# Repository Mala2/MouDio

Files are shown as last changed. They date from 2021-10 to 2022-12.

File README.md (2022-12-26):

<p align="center">
     

</p>
<p align="center">
	<a href="https://github.com/Mala2/Bluetooth-Speaker/repo-size" alt="repo-size">
		</a>
	<a href="https://github.com/Mala2/Bluetooth-Speaker/issues" alt="Issues">
		</a>
	<a href="https://github.com/sparkfun/Qwiic_SerLCD_Py/blob/master/LICENSE" alt="License">
		</a>
	  <br/>
  	<a href="https://discord.gg/jvKunuGb8d">
   		
	<a href="https://twitter.com/intent/follow?screen_name=Muhammadalali">
        	</a>
	<a href="https://github.com/Mala2">
        	</a>
	<a href="https://github.com/Mala2/Bluetooth-Speaker/stargazers" alt="stars">
		</a>

<p align="center">
🚨 ⚠ This project is currently still under development ⚠️ 🚨

<p align="center">
     
   
<p align="center">
(https://www.MouDio.net)
</p>

# Overview
Introducing the fully functional Bluetooth Speaker, featuring modern design and high-performance capabilities. With the choice of ATmega328P or ESP32 microcontroller at its core and compatibility with Arduino & Platformio, this portable speaker offers easy construction, allowing users to quickly and easily set it up, and the high-quality audio ensures that your music will sound great.

The speaker also boasts the Qualcomm® CSR8675 FSC-BT806 and 2x Texas Instruments® TAS5825M amplifiers, providing low distortion and powerful output of 2 x 30 W.

The PCB prototypes have been built and tested, with excellent results. The hardware design is complete, and we are now focusing on the software development. We invite you to explore the shared files for more information on this exciting project.

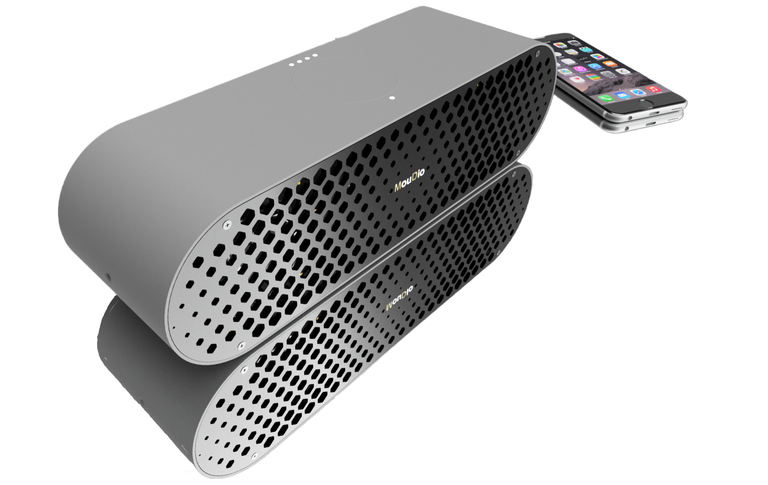
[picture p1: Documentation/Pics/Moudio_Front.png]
(https://a360.co/3340jVi)


[*🎨 View on FUSION 360*](https://a360.co/3Bk0sSi)
<p align="center">
     

# Features
	
* **Amplifier** - 2x  Texas Instruments® [*TAS5825M*](https://www.ti.com/product/TAS5825M) Which has low distortion can output 2x 30 W, 2.2 Mode (8-Ω, 24 V, THD+N=1%)
* **Connectivity** - The [*FSC-BT806 Feasycom*](https://github.com/Mala2/FSC-BT806) features
 Qualcomm® **CSR8675** - **Bluetooth V5.0** Support HSP, HFP, A2DP, AVRCP, PBAP,MAP,SPP,BLE profile - Coverage up to 15m - 2 microphone inputs - **Audio interfaces:** I²S/PCM and SPDIF

* **Power** - Accept **USB C IN** Delivery **Up to 2.5A  Charge Current**  - **USB A OUT** Capable of **10W-5V,2A** - **Low idle power** consumption - **7500mAh** battery capacity upgradeable to **15000mAh**

* **Arduino IDE Programmable Bluetooth-Speaker**
<p align="center">
     

 # Repository Contents

👩‍🚀 **[3D Files ](3D-Files)** • The **Bluetooth-Speaker** components in many formats (probably what you are looking for to 3d print)

🔉 **[Hardware](Hardware)** • The internal PCBs files (Gerber, Schematic)

💻 **[Software](Software)** • Codes and Libraries for use with the **MouDio**

📄 **[Documentation](Documentation)** • Datasheets, other references

🎲 **[Prototype](Prototype)** • Evaluation board, Cases, etc.

<p align="center">
     

# Block Diagram

The following displays the latest Block Diagram; Things may change, and probably there may be some discrepancy between the schematic and the block diagram.
	


<p align="center">
     

# Schematics

The following displays the ****[TOP Main](Documentation/TOP-Main/)**** PCB. It contain the Atmega328|ESP32 uC, LED Driver, Haptic Driver, RTC, Touch Sensor (TPR54|48), EEPROM*, Supervisory, Addressable LEDs
	

	


****[V1](Hardware/TOP/)****
	
[📐 *View on FUSION 360*](https://a360.co/3VPY0L3)

<p align="center">
     
	
The following displays the ****[BACK Charger](Documentation/BACK-Charger/)**** PCB.It contain MAX77961 3S Charger, MAX17320 Fuel Gauge, MAX25231ATCA 5V Buck, MAX77503BEWC33 3V3 Buck, 3S Battery.


	



****[V1](Hardware/BACK/)****
	
[📐 *View on FUSION 360*](https://a360.co/3UELmh8)
	
<p align="center">
     
	
The following displays the ****[BOTTOM Amplifier](Documentation/BOTTOM-Amplifier/)**** PCB.It contain the Amplifier - 2x Texas Instruments® TAS5825M and The FSC-BT806 Feasycom Bluetooth Moduel.


	

	
	
****[V1](Hardware/BOTTOM/)****	
	
[📐 *View on FUSION 360*](https://a360.co/3FziKBq)

<p align="center">
     
	
The following displays the ****[FRONT Speaker](Documentation/FRONT-Speaker/)**** PCB.To hold the Speakers and front acrylic grill


	



****[V1](Hardware/FRONT/)****
	
[📐 *View on FUSION 360*](https://a360.co/3BfI0KE)

<p align="center">
     	

# Working Principal

**1. First, I am going to use the TPR54 Touch Sensor Modules to turn ON/OFF the system, if pin [I/O-2] "TAP" it is pressed >2s. This module can send  active High signal output to the ATmega328p pin 2 [INT0].**

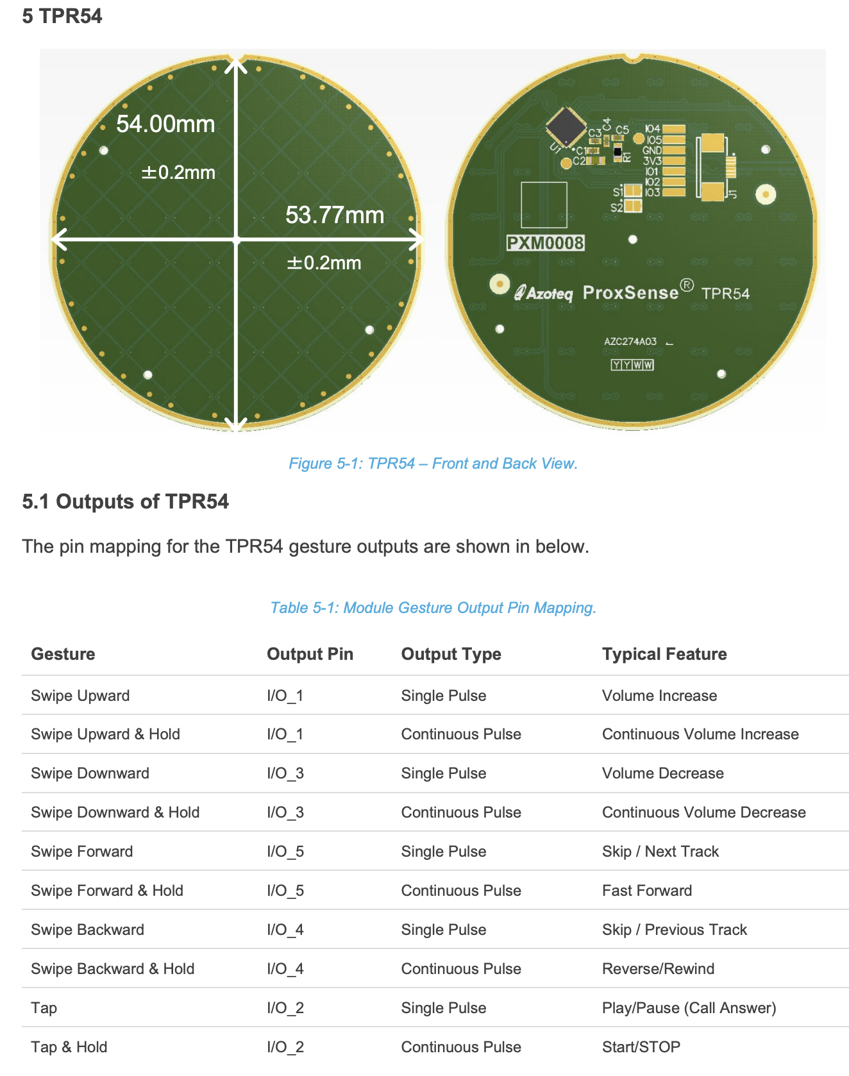
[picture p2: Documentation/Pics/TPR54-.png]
(https://www.azoteq.com/images/stories/pdf/proxsense_gpio_trackpad_datasheet.pdf)


**2. After waking up, the ATmega328 will send a high signal to turn on the Bluetooth Module BT-806 through pin [8] "Vreg" and the TAS5825 circuitry through pin [A3] "PDN".**

🔸	**Startup Procedures: [I/O_2] "TAP" pressed for >2s**

*	The ATmega328p wakes up upon High signal on pin 2 [INT0].

*	Send a 3V3 high signal to haptic driver to enable the IC.

*       initialize the LED driver IS31FL3195 to wakeup.

*	Turn on the haptic driver as an indication for 1s.

*	Turn on the LED driver to play a motion from left to right as wake up inication.

*	Turn on the LED driver to reflect the current SOC% of the battery with the help of the fuel gauge MAX17320 and check whether the charger is presnt or not set the LEDs accordingly. 

*	Send a 3V3 high signal of more than 100ms to Bluetooth Module BT-806 through VREG_IN (PLAY/PAUSE) pin to boot the module, then bring the signal back to low.

*	Once power supplies are stable, bring up PDN of TAS5825 to High and wait 5ms.

*	Set the Amplifier TAS5825 into the HiZ state and enable DSP via the I2C control port.

*	Wait 5ms at least. Then initialize the DSP Coefficient, then set the TAS5825 to Play state.

*       initialize the charger MAX77961.

	<br />
	
🔸	**Shutdown Procedures: [I/O_2] "TAP" pressed for >2s**

*	Configure the Register 0x03h -D[1:0]=10 (Hiz) via the I2C control port and Pull PDN low.

*	Wait at least 6ms (this time depends on the LRCLK rate, digital volume, and digital volume ramp-down rate).

*	Send a 3V3 high signal of more than 100ms to Bluetooth Module BT-806 through VREG_IN (PLAY/PAUSE) pin to turn off the module, then bring the signal back to low.

*	The ATmega328 goes to deep sleep, waiting for the next event.
	
	<br />

🔸	**Charging Procedures:**

*	Once the charge input is present, the MAX77961 will send an interrupter either through INTB, INOKB pins

*	Turn on the haptic driver as an indication for 1s.

*	Display the current SOC% with 4 LEDs with the help of an LED driver as long as the charge input is present. Otherwaise, the ATmega328 goes to deep sleep, waiting for the next event.

<br />
	
**3. Once the speaker is ON, the TPR54 is responsible for interacting with Bluetooth Module BT-806 to change the song and volume. (Keep in mind that the TAS5825 can also change just the volume) through TX/RX UART pin between the ATmega328 and Bluetooth Module BT-806 at 115200 rate data. For example: Once the ATmega328 is connected to BT-806, It can send a command to change the volume. For example,**



**And so on. Also, if the BAT SOC% is low, alert the user with an LED blinking and start the Shutdown Procedures once the BAT is too low to operate the system > 15%.**

# To Do List

♦️ **Need help with software part.**

1- After making sure the BT806 is OFF through the commands AT+, Turns the BT806 after turning the 3v3. Sending a high signal to Vreg for > 2s upon waking up, then remain Low. (OR MOSFET NETWORK)
	
2- If the battery is < 15%, shut down the speaker if no charging is present.
			     
✅ 3- If the battery is <35%, set the MAX volume to be less than 70%. In other words, it reduces the volume to not consume more power. TAS5825 has register 0x4c and 0x54 (AGAIN or DIGITAL_VOL) to set that.

4- (after checking the vol range of bt806), send a command AT+SPKVOL and check the volume range of BT806 sent. After that, set the TAS5825 accordingly; that can be done with two registers, either 0x4c and 0x54 (AGAIN or DIGITAL_VOL).
	
✅ 5- For example, once the user swap to the right (Next Song). The LEDs should indicate that from left to right emotions.

6- If no sounds or connection is established for 30 min, turn off the speaker. Either by checking the current flow from the fuel gauge MAX17320 or the BT-806 is not in play status or the TAS5825 register 0x03 is mute status for more than 30 min.

✅ 7- If the charger is inserted, activate the haptic driver as feedback.

9- If the charger is inserted, increase the volume range to be even higher as more power will be provided. This can be done if the 0x4C register is changed accordingly with the attached and disattached of the charger.

10- Add resetFunc() after touching the middle TAP more than 10s.

11- Get the header file for the TAS5825M to act as Dual stereo 2.2 and output the best sounds. You need PPC3 software and hardware access to test the setup and extract the best DSP settings.

12- Create the initialization code configuring the bq28z610 fuel gauge to work with the Arduino Uno and create a Library, and also create a “control” object for the bq28z610 fuel gauge. This includes configuring the IC’s registers via I2C to set configurations. In addition, looking to expose all features of the target ICs in code so that a user can easily configure those features using variables.

♦️ TO BE CONTINUED
	<p align="center">
     
# Components

🔷 **Speakers**

<p align="center">
     

[*ND65-8 2-1/2"*](https://www.parts-express.com/Dayton-Audio-ND65-8-2-1-2-Aluminum-Cone-Full-Range-Driver-8-290-206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) **X2**

🔷 **Tweeters**

<p align="center">
     

[*ND20FA-6 3/4"*](https://www.parts-express.com/Dayton-Audio-ND20FA-6-3-4-Soft-Dome-Neodymium-Tweeter-275-030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) **X2**

🔷 **Acousta-Stuf Polyfill**

<p align="center">
     

[*Acousta-Stuf Polyfill*](https://www.parts-express.com/Acousta-Stuf-Polyfill-1-lb.-Bag-260-317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)

🔷 **Brass Threaded Metal**
M3 3mm M3-0.5 Brass Threaded Metal Heat Set Screw Inserts for 3D Printing

<p align="center">
     

[*Brass Threaded Metal*](https://www.ebay.com/itm/292174792941)

🔷 **Silicone Rubber Mat 60x8x3mm**

<p align="center">
     

[*Silicone Rubber Mat*](https://www.aliexpress.com/item/3256801841973589.html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)**X2**

Mo's github stats (https://github.com/anuraghazra/github-readme-stats)
<p align="center">


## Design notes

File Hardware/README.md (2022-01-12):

Components
========================================

Speakers
--------------
ND65-8 2-1/2" (https://www.parts-express.com/Dayton-Audio-ND65-8-2-1-2-Aluminum-Cone-Full-Range-Driver-8-290-206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)

[*ND65-8 2-1/2"*](https://www.parts-express.com/Dayton-Audio-ND65-8-2-1-2-Aluminum-Cone-Full-Range-Driver-8-290-206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) **X2**

OR

[*ND65-4 2-1/2"*](https://www.parts-express.com/Dayton-Audio-ND65-4-2-1-2-Aluminum-Cone-Full-Range-Driver-290-204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) **X2**

Tweeters
--------------
Tweeters (https://www.parts-express.com/Dayton-Audio-ND20FA-6-3-4-Soft-Dome-Neodymium-Tweeter-275-030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)

[*ND20FA-6 3/4"*](https://www.parts-express.com/Dayton-Audio-ND20FA-6-3-4-Soft-Dome-Neodymium-Tweeter-275-030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) **X2**

Chemcast Black LED Acrylic
--------------
Chemcast Black LED Acrylic (https://www.tapplastics.com/product/plastics/cut_to_size_plastic/black_led_sheet/668)

[*Chemcast Black LED Acrylic*](https://www.tapplastics.com/product/plastics/cut_to_size_plastic/black_led_sheet/668) **X1** For the front panel done by laser cut

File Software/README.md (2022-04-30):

To Do List
-------------------
	
🔴 **Need help with software part.**

1- ✅ Turns the bt806 after turning the 3v3. Sending a high signal to Vreg for > 2s Upon waking up then remain Low. (OR MOSFET NETWORK)

2- ✅ if the battery < 15% shut down the speaker. 

3- ✅ if the battery <35% set the MAX volume to be less than 70%. In other words reduces the volume to not consume more power. TAS5825 has register 0x4c and 0x54 (AGAIN or DIGITAL_VOL) to set that.

4- (after checking the vol range of bt806), send a command AT+SPKVOL and check the volume range of bt806 sent. After that set the TAS5825 accordingly. That can be done with two registers either  0x4c and 0x54 (AGAIN or DIGITAL_VOL).

5- ✅ For example once the user swap to right (Next Song). The leds should indicate that. From left to right emotions ->.

6- If no sounds or connection established for 30 min turn off the speaker. Either by checking the current flow from the fuel gauge or the BT-806 is not in play status for more than 30 min. Also, it can be done through GPIO1 of TAS5825 as it will set HIGH/LOW once no sound signal is coming. 

7- ✅ If charger inserted activate the haptic driver as a feedback.

9- If the charger is inserted increase the volume range to be even higher as more power will be provided. 
	
10- add resetFunc() after touching the middle TAP more than 10s. 
	
11- get the header file for the TAS5825M to act as  Dual stereo 2.2.  
	
🔴 **To be continued

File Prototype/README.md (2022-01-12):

Bunch of Evaluation boards to determain the best suitable ICs to implement on the final design.

Please refer to the shared files for more information about specific PCB.

🎨 📐 FUSION 360 (https://d2t1xqejof9utc.cloudfront.net/screenshots/pics/dff4e49b7d47001b7a706a3b311ecfec/original.png)

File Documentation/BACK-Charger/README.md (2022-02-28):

This PCB has the Atmega328, RP2040 uC, and MAX77962 2S charger IC, BQ28Z610 Fuel Gauge IC, IS31FL3195 LED Driver IC, DRV2605 Haptic Driver IC

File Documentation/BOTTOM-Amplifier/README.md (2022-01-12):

# Main-PCB
<p align="center">

This PCB has the amplifier, and Bluetooth module BT-806 

🔴 Amplifier (TAS5825)	<a href="https://www.ti.com/product/TAS5825" alt="repo-size">
		</a>
-------------------
 The reason behind this choice contains a lot of factors. There was many potential Amplifiers for this design. Including:

To choose the suitable one I considered the key measurements are:

- SNR
- PSRR
- Efficiency
- CMRR
- Quiescent current
- THD+NOISE
- Output noise
- Crosstalk

For the SNR (Signal-to-noise ratio):

1. 🔹TPA3116, TPA3130 **102db**
2. MAX98306 ➡️ **99db**
3. SSM2302 ➡️ **98db**
4. MAX9736 ➡️ **97db**
5. PAM8403 ➡️ **80db**

**Clearly the winer here is TPA3130, TPA3116**

For the PSRR (Power supply rejection ratio):

**TPA3130 along with MAX98306 has the best performance**

For the Efficiency:
1. MAX98306 ➡️ **92\%**
2. 🔹TPA3130 ➡️ **90\%**
3. MAX9736 ➡️ **88\%**
4. PAM8403 ➡️ **87\%**
5. SSM2301 ➡️ **85\%**

**Again TPA3130 along with MAX98306 has the best performance**

For the CMRR (Common-mode rejection ratio):
1. MAX98306 ➡️ **79db**

No available data for the rest

 For the  Quiescent current:

1. MAX98306 ➡️ **2 mA**
2. 🔹TPA3130 ➡️ **4 mA**
3. PAM8403 ➡️ **16 mA**
4. MAX9736 ➡️ **30 mA**
5. TPA3116 ➡️ **32 mA**

For the THD+NOISE:

**Most of the amplifiers has approximately the same results.**

For the Output noise:

1. MAX98306 ➡️ **29uV**
2. SSM2302 ➡️ **35uV**
3. 🔹TPA3130 ➡️ **65uV**
4. MAX9736, PAM8403 ➡️ **100uV**

**We can see how **MAX98306** has a good performance**

Lastly the Crosstalk:  
1. MAX98306
2. 🔹TPA3130
3. SSM2302
4. MAX9736
5. PAM8403

**Again TPA3130 along with MAX98306 has the best performance**

Final Decision  
-------------------

**MAX98306 and (TPA3130 OR TPA3129) has the best results even though MAX98306 is better I would rather choose (TPA3130 OR TPA3129) for the output power reaching 30W in Mono setup and 2X15W in Stereo setup while MAX98306 can only output 3.7W which wasn’t enough for this Design.**

 TPA3130 and TPA3129 Both have the same footprint which make it easier to populate either one. The difference is that TPA3129 has **Low idle power** consumption. Both are capable of outputing 30W , 2X15W.

	🔺 **TAS5825M OR TAS5825P** Will be the upgrade of the (TPA3130 OR TPA3129) since it has lower distortion and built in DSP (Digital Signal Processing), plus it can output 38-W stereo which is more than enough. Only draw back is it does needs uC to configure it.

🔴 Bluetooth module (BT-806)   <a href="https://www.feasycom.net/dual-mode-bluetooth-module/bluetooth-5-0-csr8675-aptx-audio-module-fsc.html
" alt="repo-size">
		</a>
-------------------

The Bluetooth module is critical piece of the design, a lot of thoughts went into this. The [*FSC-BT806 Feasycom*](https://github.com/Mala2/FSC-BT806) has a great module which integrate the Qualcomm® CSR8675 - Bluetooth V5.0 Support HSP, HFP, A2DP, AVRCP, PBAP,MAP,SPP,BLE profile - Coverage up to 15m - True Wireless Stereo to share BT audio stream between two Speakers - Wired analog input.

This chip can output stero mode with high sound quality, plus it is easy to program which I did not get deep into. I was able to change the Bluetooth discoverable name as I wish. Through **TX/RX** pins it can communicate to other microcontrollers. I for sure haven’t used all the potential futures this Module can offer due to my luck of coding experience. Otherwise this chip is a uC and can be the master mind to control all this chips this design needs through I2C, PIOs, AIOs and LEDs for status indications (Low Battery, Bluetooth Status). Also, it supports **ANCS** The purpose of the Apple Notification Center Service (ANCS) is to give Bluetooth accessories (that connect to iOS devices through a Bluetooth low-energy link) a simple and convenient way to access many kinds of notifications that are generated on iOS devices. Finally, it can charges the battery with 200mA which wasn’t practical in this design since it has 5000mAh battery which will take up to 25 Hours for full charge. However, it would be suitable for smaller Speaker design.

To be continued ...

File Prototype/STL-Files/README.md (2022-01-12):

[*🎨 📐View and Download on FUSION 360*](https://a360.co/3340jVi)

Downloadable formats:

**STL**

**FBX**

**STEP**

**DWG**

**DXF**

**OBJ**

# Print Settings


Printer brand:
**Creality**

Printer:
**Ender-3**

Rafts:
**Doesn't Matter**

Supports:
**YES**

Resolution:
**Recommended 0.12mm** but 0.28 is alright

Infill:
**25%**

Nozzle:
**0.2-0.4mm**

Filament brand:
[**AMOLEN**](https://www.amazon.com/gp/product/B0721SVW3L/ref=ppx_yo_dt_b_asin_title_o01_s00?ie=UTF8&psc=1)

Filament color:
**Marble**

Filament material:
**PLA**

Software:
**Cura**

Notes:
The Ender-3 plate in Cura won't fit the Main body, so we have to extend the plate dimensions by a bit from Cura settings. Also, enable ironing choice for smoother finishing

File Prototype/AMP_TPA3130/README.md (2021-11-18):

I added there diffrent PCBs design on the **[PCM1820](/Prototype/ADC_PCM1820/)** PCB for the input capacitor to test diffrent values and Cap materials.

Input capacitors
-------------------

•  **Film SMT Caps** P/N: 4.7uF [35MU475KC44532](https://www.digikey.com/en/products/detail/rubycon/35MU475KC44532/9951738) 

•  **CER SMD Caps** P/N: 1uF [C1608X7R1C105K080AC](https://www.digikey.com/en/products/detail/tdk-corporation/C1608X7R1C105K080AC/634395) - 4.7uF [CGA4J3X7R1C475K125AB](https://www.digikey.com/en/products/detail/tdk-corporation/CGA4J3X7R1C475K125AB/2672862) - 10uF [CC0805KKX7R5BB106](https://www.digikey.com/en/products/detail/yageo/CC0805KKX7R5BB106/5195283)
 
•  **Film TH Caps** P/N: 4.7uF [R75PW447050H3J](https://www.digikey.com/en/products/detail/kemet/R75PW447050H3J/12144250) 

I added a dot • to indicate the right corresponding position to the main PCB

Those little PCBs can also be mounted as an **Input capacitors** on the **[PCM1820](/Prototype/ADC_PCM1820/)** PCB

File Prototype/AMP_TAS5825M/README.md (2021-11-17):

# TAS5825M OR TAS5825P

It is a class D amplifier with 90 mΩ RDS. It can output 2 × 30 W, at 24V on 8Ω driver load.

I initially intended to use **TAS5825M** but I found out that **TAS5825P** has Hybrid Pro algorithm to extend the battery life by more than 50% and it is pin-pin compatible with **TAS5825M**.

The [*FSC-BT806 Feasycom*](https://github.com/Mala2/FSC-BT806) can output analog which can be fed to the ADC **PCM1820** PCB to output 32-bits, 2-channel I2S/TDM then that can be fed to amplifier **[TAS5825M](/Prototype/AMP_TAS5825M/)** PCB. Also,The [*FSC-BT806 Feasycom*](https://github.com/Mala2/FSC-BT806) can output 2-channel I2S to directly connect to **[TAS5825M](/Prototype/AMP_TAS5825M/)** PCB if that desirable.

Power Supply 
-------------------
Voltage: 4.5-26V, recommended 12-24V

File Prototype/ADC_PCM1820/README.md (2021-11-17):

# PCM1820

It is an **ADC** with resolution of 32-bit I2S/TDM

The [*FSC-BT806 Feasycom*](https://github.com/Mala2/FSC-BT806) can output analog which can be fed to the ADC **PCM1820** PCB to output 32-bits, 2-channel I2S/TDM then that can be fed to the amplifier **[TAS5825M](/Prototype/AMP_TAS5825M/)** PCB

I added there diffrent PCBs design for the input capacitor to test diffrent values and Cap materials

Input capacitors
-------------------

•  **Film SMT Caps** P/N: 4.7uF [35MU475KC44532](https://www.digikey.com/en/products/detail/rubycon/35MU475KC44532/9951738) 

•  **CER SMD Caps** P/N: 1uF [C1608X7R1C105K080AC](https://www.digikey.com/en/products/detail/tdk-corporation/C1608X7R1C105K080AC/634395) - 4.7uF [CGA4J3X7R1C475K125AB](https://www.digikey.com/en/products/detail/tdk-corporation/CGA4J3X7R1C475K125AB/2672862) - 10uF [CC0805KKX7R5BB106](https://www.digikey.com/en/products/detail/yageo/CC0805KKX7R5BB106/5195283)
 
•  **Film TH Caps** P/N: 4.7uF [R75PW447050H3J](https://www.digikey.com/en/products/detail/kemet/R75PW447050H3J/12144250) 

I added a dot • to indicate the right corresponding position to the main PCB

Those little PCBs can also be mounted as an **Input capacitors** on the **[TAS5825M](/Prototype/AMP_TAS5825M/)** PCB

Power Supply 
-------------------
Voltage: 5V choose to populate either **BL9198-33** or **LP5912-3.3** LDO. I prefare the **LP5912-3.3** as it has LOW IQ and LOW Noise

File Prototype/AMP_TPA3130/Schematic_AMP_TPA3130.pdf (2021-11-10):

A | A
B | B
C | C
D | D
E | E

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
TITLE:
AMP_TPA3130 | REV: 1.0
Date: | 2021-10-17

Sheet: 1/1
Drawn By: mfm1500

### Company: Mohammad Alabdulaziz

TAS5825M is better AMP

1D23A-100M

OR

Mouser Part #
CLF12577NIT-100M-D

100K

R33
100K

R32

100uF

C16
100uF

C33

100uF

C1

330pF

C68

330pF

C67

330pF

C66

330pF

C65

C85978
OR
FKP2D003301D00JA00

Mouser Part #
GRM1885C1H331JA01D

PGND
0.22uF
C64

0.22uF

C63

0.22uF
C62

0.22uF

C61

Mouser Part #
810-C1608X7R1H224K

MKP2F032201K00JSSD

OR

0.68uF

C60

0.68uF

C59

0.68uF

C58

OR
ECW-F2684HAB

Mouser Part #
GRM31MR71H684KA88L

0.68uF

C57

10nF

C56

10nF

C55

10nF

C53

C97925

Mouser Part #
GRM21BR72A103KA01L

MKP2G021001C00JI00

OR

10nF

C52

OR
667-ECW-FD2W475JB
RC SNUBBER

LC FILTER
https://www.ti.com/lit/an/slaa701a/slaa701a.pdf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

https://www.ti.com/lit/an/sloa201/sloa201.pdf?ts=1629522849611&ref_url=https%253A%252F%252Fwww.google.com%252F

TPA3129D2 is better AMP

OR
80-R71XR510050H0K

Mouser Part #
80-R71XN447050H0K

## Polypropylene (PP) film capacitors are best for audio

C0805X106J9RACTU

Touch pad copy

SDZ1

1

RH

Jumper

JP1

RH

GND

100nF

C23 GND

5v+ out

SDA

SCL

5017

LP1 1

1

5017

1

RP1

1 5017

LN1 1

1

5017

RN1

1

1

SPK_L_P

SPK_R_P

SPK_L_N

SPK_R_N

DS1841N+

U8

SDA 1

GND 2
VCC 3

A1 4

A0 5

RGND 6

RW 7

RH 8

NC 9

SCL 10

EP 11

DS1841

https://ohmslawcalculator.com/voltage-divider-calculator Should be 10uF

2 15 W Into a 8- BTL Load at 15 V

C=0.22uF

100uF

C34

12V

YOU SHOULD SEPARATE THEM NEAR THE DEVICE

SGND= SIGNAL GND

PGND= POWER GND

SDZ: HIGH = ON

Replace it with 10k as if digital used

12V

MUTE

EN AMP

12V

GND
3.32

3.32

3.32

## TPA3130D2

## Amplifier

https://www.ti.com/product/TPA3130D2

PGND

100nF

C70
1000pF

C72

RP

J19
R+
R65

PGND

PGND

10uH

L14

10

10

10

R72
OUTPR | PGND BSPR

OUTNR

RN

J20
R-

PGND

R66

PGND

10uH

L13

R71
PGND BSNR

BSPL
OUTPL

LP

J21
L+

PGND

R67

PGND

10uH

L12

PGND

R70

LN

J22
L-

PGND

3.32

R68

PGND

10uH

L11

10 PGND
R69

OUTNL
BSNL

PGND

100nF

C71
1000pF

C73

PGND | SGND

SGND

47pF

C75

4.7K

R62

SGND

100K R61

SGND

1uF

C74

47K

R63

75K

R64

PLIM

LIN-

RIN-

LIN+

RIN+

SDZ

PGND

TPA3130D2DAPR

U16

MODESEL 1
SDZ 2
FAULTZ 3
RINP 4
RINN 5
PLIMIT 6
GVDD 7
GAIN/SLV 8
GND 9
LINP 10
LINN 11
MUTE 12
AM2 13
AM1 14
AM0 15
SYNC 16 | AVCC 17 PVCC 18 PVCC 19 BSNL 20 OUTNL 21 GND 22 OUTPL 23 BSPL 24 GND 25 BSNR 26 OUTNR 27 GND 28 OUTPR 29 BSPR 30 PVCC 31 PVCC 32 EPAD ³³

4.7uF

C79
LIN-

RIN-

4.7uF

C78

LIN+

RIN+

4.7uF

C77

4.7uF

C76

LIN

RIN

https://www.ti.com/tool/PMP9491

Next time: you can use variable resistor controled with microcontrollers to set the gain "I2C protocol"

## Amplifier

HDR-M-2.54_1x10

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
HDR-M-2.54_1x1

J2

1
SPK_L_N

EN AMP

MUTE

SPK_R_P

SDA

SPK_R_N

SCL

SPK_L_P

12V

5v+ out

GND

GND

5.23K

R1
SDA

SCL

5v+ out

5.23K

R2

## Signal Level Sensor System needed

## Lower impedance speakers = more power = more current =more heat = more distortion

https://www.ti.com/lit/an/slyt796/slyt796.pdf?ts=1634908388064

## increasing resistance of line impedance or increasing capacitance is good to reduce distortion

OR
35MU475KC44532

C1608X7R1C105K080AC1uF
CC0805KKX7R5BB10610uF

0.22uF PHE426HJ6220JR05

0.68uF | ECW-FD2W684K4
1uF | GCJ21BR71H105KA01L

4.7uF CGA4J3X7R1C475K125AB

CRCW06033R32FKEA

Replacment

08055C102KAT2A
100nF 08055C104KAT2A

3.32

1000pF

330pF FKP2J003301D00HSSD

10 RN73H1JTTD10R0F100

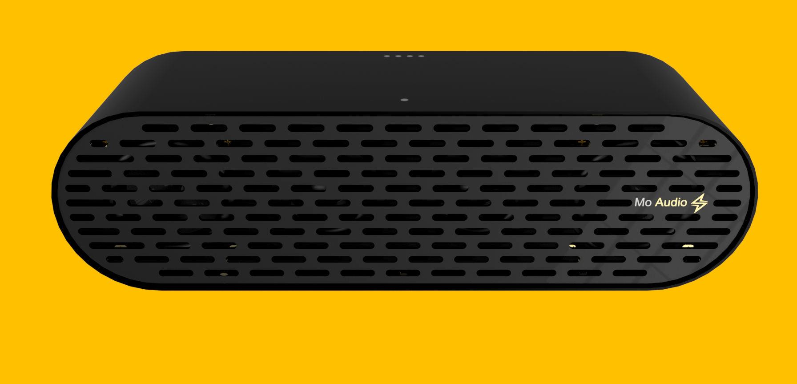
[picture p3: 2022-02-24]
Documentation/Pics/SPK2.png

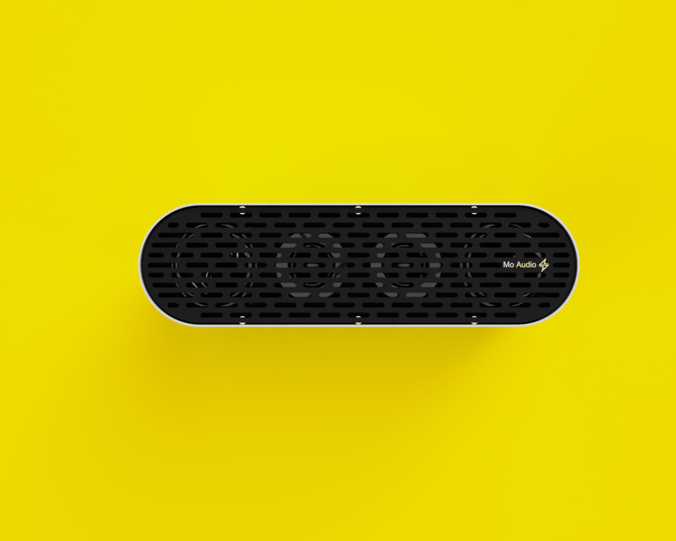
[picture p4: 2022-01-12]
Documentation/Pics/front yel.png

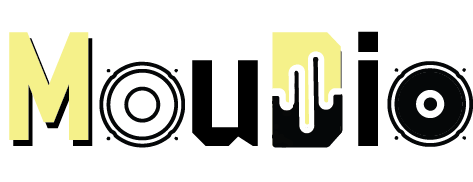
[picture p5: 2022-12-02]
Documentation/Pics/Moudio.png

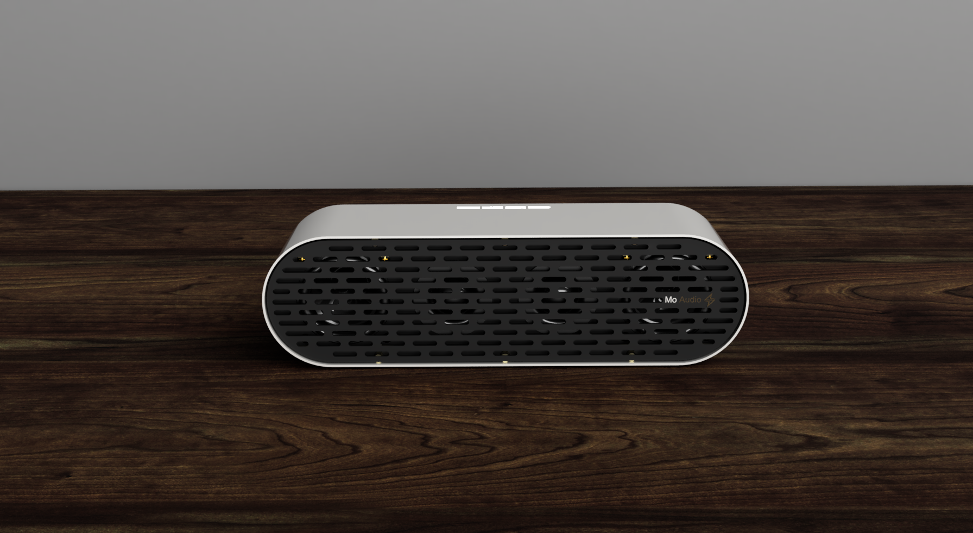
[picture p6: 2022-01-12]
Documentation/Pics/front 1.png

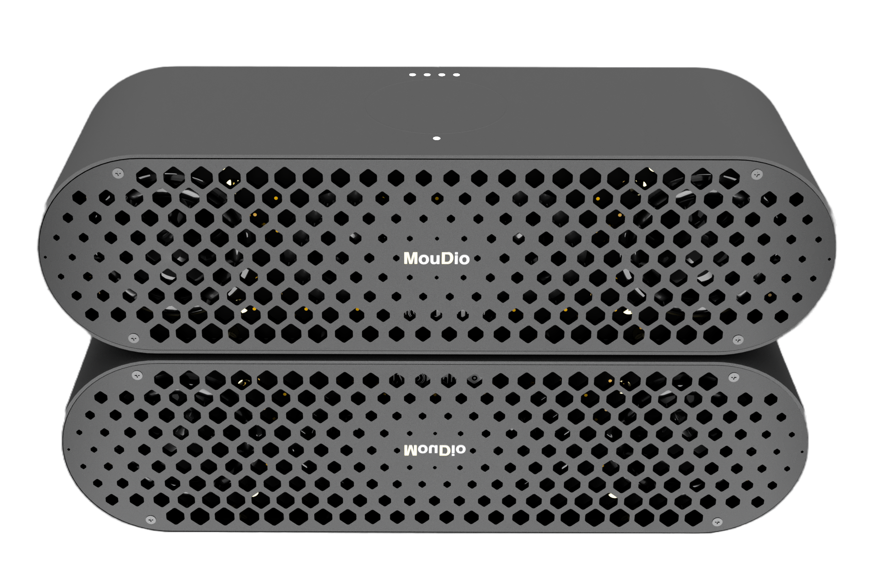
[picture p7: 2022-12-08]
Documentation/Pics/Moudio_Frontpage.png

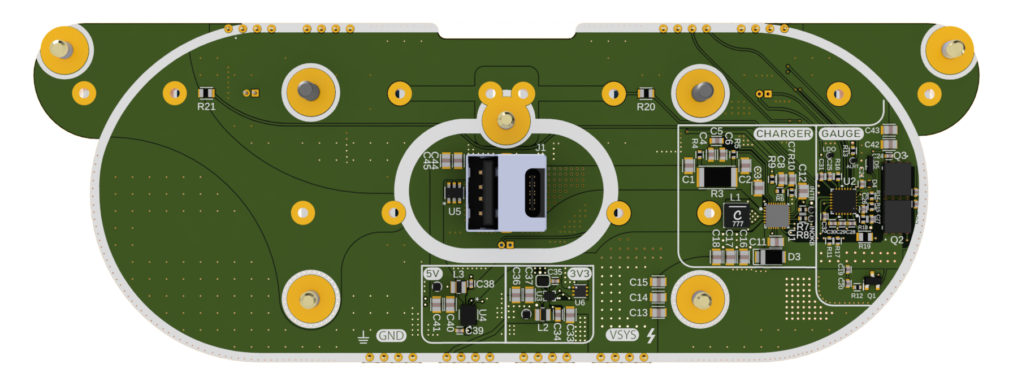
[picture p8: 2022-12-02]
Documentation/Pics/BACK_Charger_B.png

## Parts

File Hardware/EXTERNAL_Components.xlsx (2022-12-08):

Country of Origin may be different at time of shipment.
The HTSUS and ECCN information shown is for informational purposes only and is not a representation or warranty as to the accuracy or reliability of these classifications. All information is provided "as is" and is subject to change without notice. Any use made of the information provided is without recourse to Digi-Key and at the user's risk.
Index | Manufacturer Part Number | Manufacturer Name | Description | Availability | Stock Status | Attrition % | Requested Quantity 1 | Pack Quantity 1 | Pack Type 1 | Digi-Key Part Number 1 | Unit Price 1 | Extended Price 1 | Minimum Order Quantity 1 | Customer Reference | Requested Part Number | Lead Weeks | Datasheet | Reference Designator | US Import Tariff | Note | Part Status | RoHS Status | ECCN | HTSUS | Country of Origin | Environmental Information | Original Part numbers | Image
1 | MPMS 003 0005 PH | B&F Fastener Supply | MACH SCREW PAN HEAD PHILLIPS M3 | 8,200 | In Stock |  | 100 | 100 | Bulk | H742-ND | 0.06600 | $6.60 | 100 |  | MPMS 003 0005 PH | 2 | http://www.fasnetdirect.com/refguide/MetD7985a.pdf |  | N/A |  | Active | ROHS3 Compliant | EAR99 | 7318.15.4000 | United States |  | MPMS 003 0005 PH | https://media.digikey.com/photos/Building%20Fasteners%20Photos/MPMS%20003%200005%20PH.JPG
2 | TPR54-P201-S | Azoteq (Pty) Ltd | 54MM ROUND GESTURE TRACKPAD | 0 | Normally Stocking |  | 1 | 1 | Bag | 1790-1010-ND | 4.75000 | $4.75 | 1 |  | 1790-1010-ND | 28 | https://www.azoteq.com/images/stories/pdf/proxsense_gpio_trackpad_datasheet.pdf |  | N/A |  | Active | RoHS Compliant | EAR99 | 8473.30.1180 | South Africa |  | 1790-1010-ND | https://media.digikey.com/Photos/Azoteq%20%28Pty%29%20Ltd/TPR54-P201-S.JPG
3 | 4255 | Adafruit Industries LLC | BRASS HEAT-SET M3X4M 1=BAG/50PCS | 21 | In Stock |  | 1 | 1 | Bulk | 1528-4255-ND | 5.95000 | $5.95 | 1 |  | 4255 | 2 | https://media.digikey.com/pdf/Data%20Sheets/Adafruit%20PDFs/4255_Web.pdf |  | N/A | Alternative:https://www.ebay.com/itm/292174792941 | Active | Unknown | EAR99 | 7419.80.5050 | China |  | 4255 | https://media.digikey.com/Photos/Adafruit%20Industries%20LLC/4255.jpg
4 |  |  |  |  |  |  | 2 |  |  |  |  |  |  |  | ND65-8 2-1/2" | N/A |  | Woofer |  | https://www.parts-express.com/Dayton-Audio-ND65-8-2-1-2-Aluminum-Cone-Full-Range-Driver-8-290-206?quantity=1 |  | - | - | - | - |  | ND65-8 2-1/2"
5 |  |  |  |  |  |  | 2 |  |  |  |  |  |  |  | ND20FA-6 3/4" | N/A |  | Tweeters |  | https://www.parts-express.com/Dayton-Audio-ND20FA-6-3-4-Soft-Dome-Neodymium-Tweeter-275-030?quantity=1 |  | - | - | - | - |  | ND20FA-6 3/4"
6 |  |  |  |  |  |  | 2 |  |  |  |  |  |  |  | Silicone Rubber Mat (60x8x3mm) | N/A |  | Pads |  | https://www.aliexpress.us/item/3256801841973589.html?_randl_shipto=US |  | - | - | - | - |  | Silicone Rubber Mat
7 |  |  |  |  |  |  | 2 |  |  |  |  |  |  |  | polyfill stuffing | N/A |  |  |  | https://www.aliexpress.us/item/2251832585574590.html?pdp_npi= |  | - | - | - | - |  | polyfill stuffing
8 | PLPC2-5MM | Bivar Inc. | LIGHT PIPE PNL MNT 2MM RND 5MM | 22,259 | In Stock |  | 5 | 5 | Bag | 492-1996-ND | 2.17000 | $10.85 | 1 |  | 492-1996-ND | 22 | https://www.bivar.com/parts_content/Datasheets/PLPC2-XXX.pdf |  | N/A |  | Active | ROHS3 Compliant | EAR99 | 3926.90.9985 | China | https://www.bivar.com/part_content/rohs/?PLPC2-5MM | 492-1996-ND | https://media.digikey.com/Photos/Bivar%20Inc%20Photos/MFG_PLPCx-Series.jpg
9 |  |  |  |  |  |  | 2 |  |  |  |  |  |  |  | Passive Radiator | N/A |  |  |  | https://www.amazon.com/uxcell-Radiator-Auxiliary-Vibration-Subwoofer/dp/B07WC9Z3JX |  | - | - | - | - |  | Passive Radiator
10 |  |  |  |  |  |  | 8 |  |  |  |  |  |  |  | Black, M2, 5mm | N/A |  |  |  | https://www.aliexpress.us/item/3256801577619187.html?_randl_shipto=US |  | - | - | - | - |  | Black, M2, 5mm

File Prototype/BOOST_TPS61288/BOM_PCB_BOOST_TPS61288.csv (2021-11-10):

ID | Name | Designator | Footprint | Quantity | Manufacturer Part | Manufacturer | Supplier | Supplier Part | Price
1 | KSC621JLFS | SW1 | KEY-SMD_4P-L6.2-W6.2-P4.00-LS6.8 | 1 | KSC621JLFS | C&K | LCSC | C221760 | 0.67
2 | HDR-M-2.54_1x5 | J2 | HDR-M-2.54_1X5 | 1 |  |  | LCSC | C358687 | 0.024
3 | MAX16054AZT+T | U2 | TSOT-23-6_L2.9-W1.6-P0.95-LS2.8-TL | 1 | MAX16054AZT+T | MAXIM | LCSC | C79401 | 1.487
4 | 100nF | C1,C13 | C0805 | 2 | 08055C104KAT2A | AVX | LCSC | C123316 | 0.013
5 | TPS61288RQQR | U1 | TPS61288 | 1 | TPS61288 |  | Digi-Key | TPS61288
6 | 100nF | C2,C4 | C0603 | 2 | GCM188R71H104KA57D | MuRata | LCSC | C85864 | 0.009
7 | 22uF | C3,C9,C10,C11,C12 | C0805 | 5 | CL21A226MAQNNNE | SAMSUNG | LCSC | C45783 | 0.02
8 | 4.7uF | C6 | C0805 | 1 | CL21A475KAQNNNE | SAMSUNG | LCSC | C1779 | 0.013
9 | 39nF | C7 | C0603 | 1 | CC0603KRX7R9BB393 | YAGEO | LCSC | C107091 | 0.007
10 | 100pF | C8 | C0603 | 1 | CC0603JRNPO9BN101 | YAGEO | LCSC | C14665 | 0.003
11 | HDR-M-2.54_1x4 | J1 | HDR-M-2.54_1X4 | 1 |  |  | LCSC | C124378 | 0.028
12 | 2.2uH | L1 | XAL7070332MEB | 1 | XAL7070-222MEC | Coilcraft | Mouser | 994-XAL7070-222MEC
13 | 44.2k | R1 | R0603 | 1 | ERA3AEB4422V | PANASONIC | LCSC | C491133 | 0.065
14 | 41.2K | R2 | R0603 | 1 | ERJ3EKF4122V | PANASONIC | LCSC | C403211 | 0.008
15 | 1M | R3 | R0402 | 1 | 0402WGF1004TCE | UniOhm | LCSC | C26083 | 0.001
16 | Jumper | JP1 | SHORT_PADS | 1

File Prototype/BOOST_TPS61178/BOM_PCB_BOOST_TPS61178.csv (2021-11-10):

ID | Name | Designator | Footprint | Quantity | Manufacturer Part | Manufacturer | Supplier | Supplier Part | Price
1 | Touch pad copy | ENVELOPE | CASTELLATED_PAD_RECEPTOR | 1
2 | HDR-M-2.54_1x6 | J1 | HDR-M-2.54_1X6 | 1 |  |  | LCSC | C190819 | 0.033
3 | 10uF | C1,C15,C16 | C0603 | 3 | GRM188R61E106KA73D | Murata Electronics | LCSC | C344022 | 0.077
4 | 100nF | C14 | C0402_NEW | 1 | CL05B104KO5NNNC | SAMSUNG | LCSC | C1525 | 0.001
5 | 1uF | C17 | C0402 | 1 | GRM155R61A105KE01D | Murata Electronics | LCSC | C389008 | 0.007
6 | BZX84C4V3LT1G | D1 | SOT-23-3_L3.0-W1.7-P0.95-LS2.9-BR | 1 | BZX84C4V3LT1G | ON Semicon | LCSC | C152532 | 0.024
7 | BC850CLT1G | Q2 | SOT-23-3_L2.9-W1.6-P1.90-LS2.8-BR | 1 | BC850CLT1G | ON | LCSC | C78484 | 0.056
8 | BSS138K | Q3 | SOT-23-3_L3.0-W1.7-P0.95-LS2.9-BR | 1 | BSS138K | ON Semicon | LCSC | C255592 | 0.082
9 | 3.01K | R7 | R0402 | 1 | RC-02W3011FT | Guangdong Fenghua Advanced Tech | LCSC | C304603 | 0.001
10 | 10K | R8,R10,R12,R13 | R0402 | 4 | CRCW040210K0FKED | VISHAY | LCSC | C71617 | 0.007
11 | 100K | R9,R11,R14 | R0402 | 3 | CR-02FL6--100K | Viking Tech | LCSC | C279979 | 0.001
12 | 12.1 | R15 | R0402 | 1 | AC0402FR-0712R1L | YAGEO | LCSC | C226768 | 0.004
13 | 42.2K | R16 | R0603 | 1 | CRCW060342K2FKEA | Vishay Intertech | LCSC | C844563 | 0.007
14 | 1M | R17 | R0402 | 1 | AF0402JR-071ML | YAGEO | LCSC | C144054 | 0.005
15 | 10.5K | R18 | R0402 | 1 | RC0402FR-0710K5L | YAGEO | LCSC | C171695 | 0.001
16 | OPA4377AIPWR | U1,U2,U3 | TSSOP-14_L5.0-W4.4-P0.65-LS6.4-BL | 3 | OPA4377AIPWR | TI | LCSC | C130012 | 8.656
17 | 1N4148WT_C511874 | D2,D3,D4 | SOD-523_L1.2-W0.8-LS1.6-RD | 3 | 1N4148WT | Bourne Semicon (Shenzhen) | LCSC | C511874 | 0.012
18 | 47uF | C2 | CAP-SMD_BD4.0-L4.3-W4.3-FD | 1 | RVT1A470M0405 | HONOR | LCSC | C87852 | 0.028
19 | 22uF | C3,C4,C5,C9,C10,C11,C13,C18 | C0805 | 8 | CL21A226MAQNNNE | SAMSUNG | LCSC | C45783 | 0.02
20 | 100pF | C6 | C0603 | 1 | CC0603JRNPO9BN101 | YAGEO | LCSC | C14665 | 0.003
21 | 6.8nF | C7 | C0402 | 1 | GRM155R71E682KA01D | MuRata | LCSC | C113051 | 0.003
22 | 100nF | C8,C12 | C0805 | 2 | 08055C104KAT2A | AVX | LCSC | C123316 | 0.013
23 | 3.3uH | L1 | IND-SMD_L11.0-W10.2 | 1 | 74437368033 | Wurth Elektronik | Mouser | 710-74437368033
24 | CSD25404Q3T | Q1 | DFN-8_L3.0-W3.0-P0.65-BL | 1 | CSD25404Q3T | Texas Instruments | LCSC | C202154 | 0.882
25 | 348K | R1 | R0402 | 1 | RC0402FR-07348KL | YAGEO | LCSC | C273713 | 0.001
26 | 57.6K | R2,R6 | R0402 | 2 | RC0402FR-0757K6L | YAGEO | LCSC | C185408 | 0.001
27 | 75k | R3 | R0603 | 1 | CRCW060375K0FKEA | Vishay Intertech | LCSC | C844586 | 0.006
28 | 150K | R4 | R0402 | 1 | CRCW0402150KFKED | Vishay Intertech | LCSC | C481951 | 0.007
29 | 422K | R5 | R0402 | 1 | ERJ2RKF4223X | PANASONIC | LCSC | C416538 | 0.005
30 | TPS61178RNWR | U4 | VQFN-HR-13_L3.0-W3.5-P0.50-BL | 1 | TPS61178RNWR | Texas Instruments | LCSC | C127918 | 5.579

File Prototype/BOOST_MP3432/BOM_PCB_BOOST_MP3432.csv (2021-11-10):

ID | Name | Designator | Footprint | Quantity | Manufacturer Part | Manufacturer | Supplier | Supplier Part | Price
1 | 100nF | C4,C5 | C0805 | 2 | 08055C104KAT2A | AVX | LCSC | C123316 | 0.013
2 | 53.6K | R6 | R0603 | 1 | RMCF0603FT53K6 |  | Digi-Key | RMCF0603FT53K6
3 | HDR-M-2.54_1x1 | J3 | HDR-M-2.54_1X1 | 1 |  |  | LCSC | C81276 | 0.005
4 | HDR-M-2.54_1x3 | J2,J1 | HDR-M-2.54_1X3 | 2 |  |  | LCSC | C180248 | 0.236
5 | 22uF | C1,C2,C3,C6,C7,C8 | C0805 | 6 | CL21A226MAQNNNE | SAMSUNG | LCSC | C45783 | 0.02
6 | 22nF | C9 | C0603 | 1 | CL10B223KB8NNNC | SAMSUNG | LCSC | C21122 | 0.005
7 | 6.8nF | C10 | C0603 | 1 | GCJ188R71E682KA01D | Murata Electronics | LCSC | C883602 | 0.026
8 | 4.7uF | C13 | C0805 | 1 | CL21A475KAQNNNE | SAMSUNG | LCSC | C1779 | 0.013
9 | Jumper | JP1 | SHORT_PADS | 1
10 | 1.5uH | L1 | IND-SMD_L11.5-W10.0_104CDMCCDS | 1 | 104CDMCCDS-1R5MC | Sumida | LCSC | C516064 | 0.872
11 | 130K | R1 | R0603 | 1 | RTT031303FTP | RALEC | LCSC | C103275 | 0.002
12 | 27K | R2 | R0603 | 1 | 0603WAJ0273T5E | UniOhm | LCSC | C25589 | 0.001
13 | 6.8K | R3 | R0603 | 1 | AECR0603F6K80K9 | ResistorToday | LCSC | C328374 | 0.002
14 | 750K | R4 | R0402 | 1 | 0402WGJ0754TCE | UniOhm | LCSC | C43291 | 0.001
15 | MP3432 | U1 | MP3431-QFN-13 | 1 | New SchematicLib |  | Digi-Key | MP3432GL
16 | 44.2k | R5 | R0603 | 1 | ERA3AEB4422V | PANASONIC | LCSC | C491133 | 0.065
17 | 20K | R8 | R0402 | 1 | 0402WGF2002TCE | UniOhm | Mouser | C25765 | 0.001

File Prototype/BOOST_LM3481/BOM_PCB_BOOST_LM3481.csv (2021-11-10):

ID | Name | Designator | Footprint | Quantity | Manufacturer Part | Manufacturer | Supplier | Supplier Part | Price
1 | HDR-M-2.54_1x6 | J1 | HDR-M-2.54_1X6 | 1 |  |  | LCSC | C190819 | 0.033
2 | HDR-M-2.54_1x1 | J2 | HDR-M-2.54_1X1 | 1 |  |  | LCSC | C81276 | 0.005
3 | 1uF | C2,C3,C8,C9 | C0805 | 4 | 08055C105KAT2A | AVX | Mouser | 581-08055C105KAT2A
4 | 470uF | C1 | CAP-SMD_BD10.0-L10.3-W10.3-FD | 1 | APXA100ARA471MJC0G | United Chemi-Con (UCC) | Mouser | 661-PXA10VC471M
5 | XAL1010-332MEB | L1 | XAL1010 | 1 | XAL1010-332MEB | Coilcraft | Mouser | 994-XAL1010-332MEB
6 | 47nF | C4 | C0603 | 1 | GCM188R71E473KA37D | Murata Electronics | LCSC | C161218 | 0.027
7 | 2.2nF | C5 | C0805 | 1 | CL21C222JBFNNNE | SAMSUNG | LCSC | C28260 | 0.031
8 | 470nF | C6 | C0805 | 1 | 0805YC474KAT2A | AVX | LCSC | C181007
9 | 10pF | C7 | C0805 | 1 | CL21C100JBANNNC | SAMSUNG | LCSC | C1785 | 0.011
10 | 270uF | C10,C11 | CAP-SMD_BD6.3-L6.6-W6.6-FD | 2 | 16SVPG270M | PANASONIC | LCSC | C178351 | 0.985
11 | MBRD835LT4G | D1 | TO-252-2_L6.6-W6.1-P4.57-LS9.9-TL-CW | 1 | MBRD835LT4G | ON | LCSC | C28423 | 0.538
12 | CSD16321Q5 | Q1 | POWERVDFN-8_L6.2-W5.2-P1.27-LS6.0-BL | 1 | CSD16321Q5 | TI | LCSC | C129342 | 1.587
13 | 56.2K | R2 | R0402 | 1 | RC0402FR-0756K2L | YAGEO | LCSC | C183355 | 0.001
14 | 44.2k | R3 | R0603 | 1 | ERA3AEB4422V | PANASONIC | LCSC | C491133 | 0.065
15 | CRCW06033K32FKEA | R4 | R0603 | 1 | CRCW06033K32FKEA | Vishay Intertech | LCSC | C844558 | 0.006
16 | 1K | R5 | R0402 | 1 | 0402WGF1001TCE | UniOhm | LCSC | C11702 | 0.001
17 | RC0603FR-0756K2L | R6 | R0603 | 1 | RC0603FR-0756K2L | YAGEO | LCSC | C482887 | 0.002
18 | CRCW0603100RJNEA | R7 | R0603 | 1 | ERJU3RD1000V | PANASONIC | LCSC | C491168 | 0.054
19 | PA2512FKF7T0R004E | R8 | R2512 | 1 | PA2512FKF7T0R004E | YAGEO | LCSC | C728322 | 0.127
20 | 8.45K | R9 | R0603 | 1 | ERJ3EKF8451V | PANASONIC | LCSC | C403375 | 0.009
21 | 10K | R1 | RES-ADJ-TH_3P-L10.0-W10.0-P2.50-L | 1 | 3296W-1-103 | Chengdu Guosheng Tech | LCSC | C118954 | 0.171
22 | SJ | SJ7 | SJ | 1
23 | Jumper | JP1 | SHORT_PADS | 1
24 | Touch pad copy | EN2 | CASTELLATED_PAD_RECEPTOR | 1
25 | TPS22969DNYT | U1 | TPS22969DNYT | 1 |  |  | Digi-Key | TPS22969DNYT
26 | 5017 | U9 | TEST-SMD_L3.4-P1.8 | 1 | 5017 | Keystone | LCSC | C238130 | 0.413
27 | LM3481MM/NOPB | U15 | VSSOP-10_L3.0-W3.0-P0.50-LS4.9-BL | 1 | LM3481MM/NOPB | Texas Instruments | LCSC | C88133 | 0.907

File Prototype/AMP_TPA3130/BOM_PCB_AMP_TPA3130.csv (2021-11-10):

ID | Name | Designator | Footprint | Quantity | Manufacturer Part | Manufacturer | Supplier | Supplier Part | Price
1 | 5017 | RN1,LP1,LN1,RP1 | TEST-SMD_L3.4-P1.8 | 4 | 5017 | Keystone | LCSC | C238130 | 0.413
2 | CRCW08050000Z0EA | R71,R70,R72,R69 | R0603 | 4 | RN73H1JTTD10R0F100 | KOA Speer | Mouser | 660-RN73H1JT10R0F100
3 | HDR-M-2.54_1x2 | J4,J3,J23,J24 | HDR-M-2.54_1X2 | 4 |  |  | LCSC | C124375 | 0.017
4 | 5.23K | R1,R2 | R0402 | 2 | 0402WGF5231TCE | UniOhm | LCSC | C25907 | 0.001
5 | HDR-M-2.54_1x10 | J1 | HDR-M-2.54_1X10 | 1 |  |  | LCSC | C57369 | 0.039
6 | HDR-M-2.54_1x1 | J2,J19,J20,J21,J22 | HDR-M-2.54_1X1 | 5 |  |  | LCSC | C81276 | 0.005
7 | 10uH | L14,L13,L12,L11 | IND-SMD_L12.5-W12.5 | 4 | CLF12577NIT-100M-D | TDK | LCSC | C138317 | 0.784
8 | TPA3130D2DAPR | U16 | HTSSOP-32_L11.0-W6.1-P0.65-LS8.1-BL-EP | 1 | TPA3130D2DAPR | Texas Instruments | LCSC | C95206 | 7.749
9 | DS1841N+ | U8 | MAXM-T1033+1_V | 1
10 | Touch pad copy | SDZ1 | CASTELLATED_PAD_RECEPTOR | 1
11 | Jumper | JP1 | SHORT_PADS | 1
12 | 100nF | C23 | C0402 | 1 | CL05B104KO5NNNC | SAMSUNG | LCSC | C1525 | 0.001
13 | 330pF | C68,C67,C66,C65 | C_RECT_L7.0MM_W2.0MM_P5.00MM | 4 | FKP2D003301D00JA00 | WIMA | Mouser | 505-FKP2D003301D00JA
14 | 0.22uF | C64,C63,C62,C61 | C_RECT_L7.0MM_W2.0MM_P5.00MM | 4 | MKP2F032201K00JSSD | WIMA | Mouser | 505-MKP20.22/250/5
15 | 0.68uF | C60,C59,C58,C57 | ECW-F2684HAB | 4 | ECW-F2684HAB | Panasonic | Mouser | 667-ECW-F2684HAB
16 | 10nF | C56,C55,C53,C52 | C_RECT_L7.0MM_W2.0MM_P5.00MM | 4 | MKP2G021001C00JI00 | WIMA | Mouser | MKP2G021001C00JI00
17 | 100uF | C34,C16,C33,C1 | 25SEK470M | 4 | 25SEK470M | PANASONIC | Mouser | 667-25SEK470M
18 | 100nF | C70,C71 | C0805 | 2 | 08055C104KAT2A | AVX | LCSC | C123316 | 0.013
19 | 1000pF | C72,C73 | C0805 | 2 | 08055C102KAT2A | AVX | Mouser | 581-08055C102K
20 | 4.7uF | C79,C78,C77,C76 | C0805 | 4 | LMK212B7475KGHT | Taiyo Yuden | LCSC | C386057 | 0.041
21 | 47K | R63 | R0603 | 1 | RC0603FR-0747KL | YAGEO | LCSC | C105579 | 0.001
22 | 4.7K | R62 | R0603 | 1 | RC0603FR-074K7L | YAGEO | LCSC | C99782 | 0.001
23 | 3.32 | R65,R66,R67,R68 | R0603 | 4 | CRCW06033R32FKEA | Vishay Intertech | Mouser | 71-CRCW0603-3.32-E3
24 | CRCW0603100KFKEA | R61 | R0603 | 1 | CRCW0603100KFKEA | Vishay Intertech | LCSC | C844916 | 0.016
25 | CRCW060375K0FKEA | R64 | R0603 | 1 | CRCW060375K0FKEA | Vishay Intertech | LCSC | C844586 | 0.006
26 | 1uF | C74 | C0805 | 1 | 08055C105KAT2A | AVX | Mouser | 581-08055C105KAT2A
27 | 47pF | C75 | C0603 | 1 | 06035A470JAT2A | AVX | LCSC | C513324 | 0.015
28 | 100K | R33,R32 | R0402 | 2 | 0402WGF1003TCE | UniOhm | LCSC | C25741 | 0.001

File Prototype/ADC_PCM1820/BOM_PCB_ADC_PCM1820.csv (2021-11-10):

ID | Name | Designator | Footprint | Quantity | Manufacturer Part | Manufacturer | Supplier | Supplier Part | Price
1 | 4.7uF | C22,C23,C24,C25 | C0805 | 4 | LMK212B7475KGHT | Taiyo Yuden | LCSC | C386057 | 0.041
2 | HDR-F-2.54_1x4 | H5,H6,H3,H4,H1,H2 | HDR-F-2.54_1X4 | 6 |  |  | LCSC | C225501 | 0.074
3 | LP5912-3.3DRVT | U1 | WSON-6_L2.0-W2.0-P0.65-TL-EP | 1 | LP5912-3.3DRVT | TI | LCSC | C134121 | 1.13
4 | 4.7uF | C17,C20,C21,C19 | FILM CAP | 4 | R75PW447050H3J |  | Digi-Key | R75PW447050H3J
5 | 4.7uF | C14,C15,C16,C13 | C1812 | 4 | 35MU475KC44532 |  | Digi-Key | 35MU475KC44532
6 | HDR-M-2.54_1x1 | J15,J10,J14 | HDR-M-2.54_1X1 | 3 |  |  | LCSC | C81276 | 0.005
7 | 22uF | C1,C8,C11 | C0805 | 3 | C2012X5R1V226MT000E | TDK | LCSC | C338080 | 0.246
8 | 100nF | C2,C6,C9,C10 | C0805 | 4 | 08055C104KAT2A | AVX | LCSC | C123316 | 0.013
9 | 10pF | C3 | C0805 | 1 | CL21C100JBANNNC | SAMSUNG | LCSC | C1785 | 0.011
10 | 100nF | C4 | C0402 | 1 | CL05B104KO5NNNC | SAMSUNG | LCSC | C1525 | 0.001
11 | 1uF | C5 | C0805 | 1 | v | AVX | Mouser | 581-08055C105KAT2A
12 | 1uF | C7,C12 | C0805 | 2 | 08055C105KAT2A | AVX | Mouser | 581-08055C105KAT2A
13 | 4.7uF | C18 | C1206 | 1 | GRM31CR71H475KA12L | MuRata | LCSC | C77096 | 0.084
14 | HDR-M-2.54_1x2 | J1,J2,J3,J4,J9,J11 | HDR-M-2.54_1X2 | 6 |  |  | LCSC | C124375 | 0.017
15 | HDR-M-2.54_1x3 | J5,J6,J7,J8,J12 | HDR-M-2.54_1X3 | 5 |  |  | LCSC | C180248 | 0.236
16 | whiteLEDSMD | LED1,LED2 | LED0805-FD | 2 | whiteLEDSMD | KENTO | LCSC | C34499
17 | BSS138_C112239 | Q1 | SOT-23-3_L2.9-W1.6-P1.90-LS2.8-BR | 1 | BSS138 | SK | LCSC | C112239 | 0.023
18 | 44.2k | R1,R2,R3,R4 | R0603 | 4 | ERA3AEB4422V | PANASONIC | LCSC | C491133 | 0.065
19 | 220 | R5,R7 | R0402 | 2 | 0402WGF2200TCE | UniOhm | LCSC | C25091 | 0.001
20 | 10K | R6 | R0402 | 1 | 0402WGF1002TCE | UniOhm | LCSC | C25744 | 0.001
21 | PCM1820 | U2 | WQFN-20_L3.0-W3.0-P0.40-TL-EP1.7 | 1 | PCM1820 | TI | Digi-Key | PCM1820
22 | BL9198-33BAPRN | U3 | SOT-23-5_L3.0-W1.7-P0.95-LS2.8-BR | 1 | BL9198-33BAPRN | BL | LCSC | C51282 | 0.097
23 | HDR-M-2.54_1x10 | J13 | HDR-M-2.54_1X10 | 1 |  |  | LCSC | C57369 | 0.039

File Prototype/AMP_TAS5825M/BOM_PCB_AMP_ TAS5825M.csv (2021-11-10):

ID | Name | Designator | Footprint | Quantity | Manufacturer Part | Manufacturer | Supplier | Supplier Part | Price
1 | HDR-M-2.54_1x3 | J1 | HDR-M-2.54_1X3 | 1 |  |  | LCSC | C180248 | 0.236
2 | HDR-M-2.54_1x10 | J2 | HDR-M-2.54_1X10 | 1 |  |  | LCSC | C57369 | 0.039
3 | 100nF | C21 | C0402 | 1 | CL05B104KO5NNNC | SAMSUNG | LCSC | C1525 | 0.001
4 | 24LC512T-I/SN | U3 | SOIC-8_L4.9-W3.9-P1.27-LS6.0-BL | 1 | 24LC512T-I/SN | MICROCHIP | LCSC | C52088 | 1.695
5 | 1uF | C22,C19,C20 | C0805 | 3 | 08055C105KAT2A | AVX | Mouser | 581-08055C105KAT2A
6 | 10uH | L1,L2,L3,L4 | IND-SMD_L10.3-W10.4-H5.0 | 4 | 1274AS-H-100M=P3 | Murata Electronics | Digi-Key | 1274AS-H-100M=P3
7 | 0.68uF | C1,C2,C3,C4 | ECW-F2684HAB | 4 | ECW-F2684HAB | Panasonic | Mouser | 667-ECW-F2684HAB
8 | 0.22uF | C5,C6,C7,C8 | C_RECT_L7.0MM_W2.0MM_P5.00MM | 4 | MKP2F032201K00JSSD | WIMA | Mouser | 505-MKP20.22/250/5
9 | 22uF | C9,C10,C11,C12 | C0805 | 4 | C2012X5R1V226MT000E | TDK | LCSC | C338080 | 0.246
10 | 100uF | C13,C14 | 25SEK470M | 2 | 25SEK470M | PANASONIC | Mouser | 667-25SEK470M
11 | 100nF | C15,C16,C17 | C0805 | 3 | 08055C104KAT2A | AVX | LCSC | C123316 | 0.013
12 | 4.7uF | C18 | C1206 | 1 | GRM31CR71H475KA12L | MuRata | LCSC | C77096 | 0.084
13 | Jumper | JP1 | SHORT_PADS | 1
14 | 5.23K | R1,R2 | R0402 | 2 | 0402WGF5231TCE | UniOhm | LCSC | C25907 | 0.001
15 | TAS5825 | U1 | VQFN-32_L5.0-W5.0-P0.50-TL-EP | 1 | TAS5825 | Ti | Digi-Key | TAS5825
16 | B2B-XH-A (LF)(SN) | CN1,CN2 | CONN-TH_B2B-XH-A-LF-SN | 2 | - | JST Sales America | LCSC | C158012 | 0.028
17 | 10K | R3,R4,R5,R8,R9,R10 | R0402 | 6 | 0402WGF1002TCE | UniOhm | LCSC | C25744 | 0.001
18 | 1K | R6,R7 | R0402 | 2 | 0402WGF1001TCE | UniOhm | LCSC | C11702 | 0.001

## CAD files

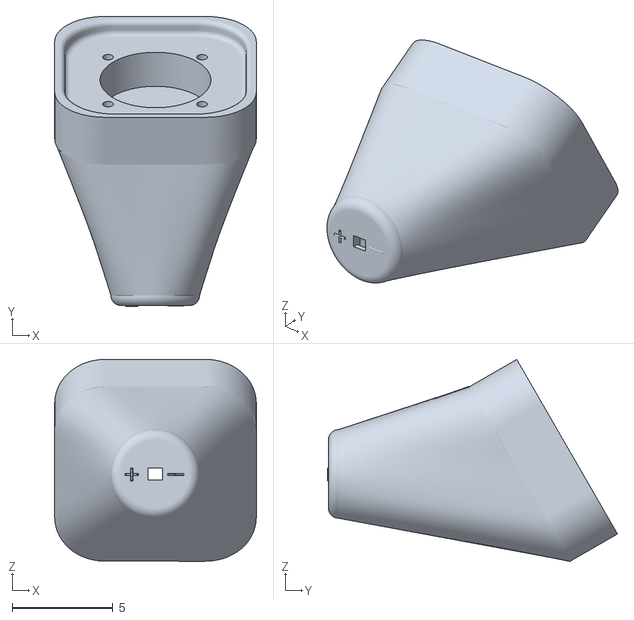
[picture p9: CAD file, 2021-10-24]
Prototype/STL-Files/Sealed Woofer Speaker Test/Main.stl
10.0 x 14.4 x 10.0

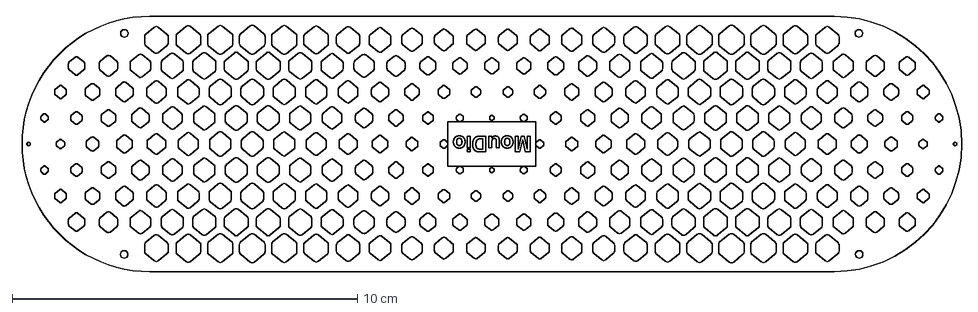
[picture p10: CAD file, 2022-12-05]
3D-Files/Grill/1/Front Pattern 1_logo.dxf
27.4 x 7.40 cm

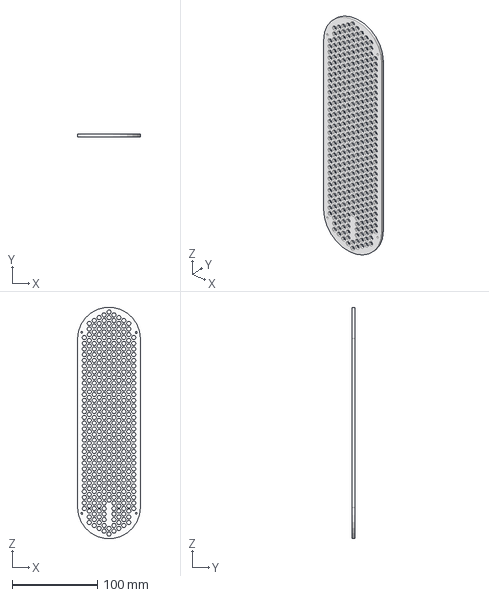
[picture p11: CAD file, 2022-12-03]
3D-Files/Grill/2/Front Pattern 2.step
74.0 x 3.00 x 271.7 mm

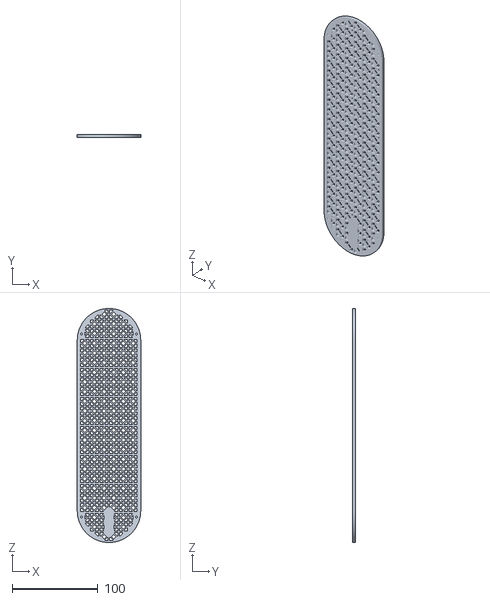
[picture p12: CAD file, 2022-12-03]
3D-Files/Grill/3/Front Pattern 3.stl
74.0 x 3.00 x 272.2

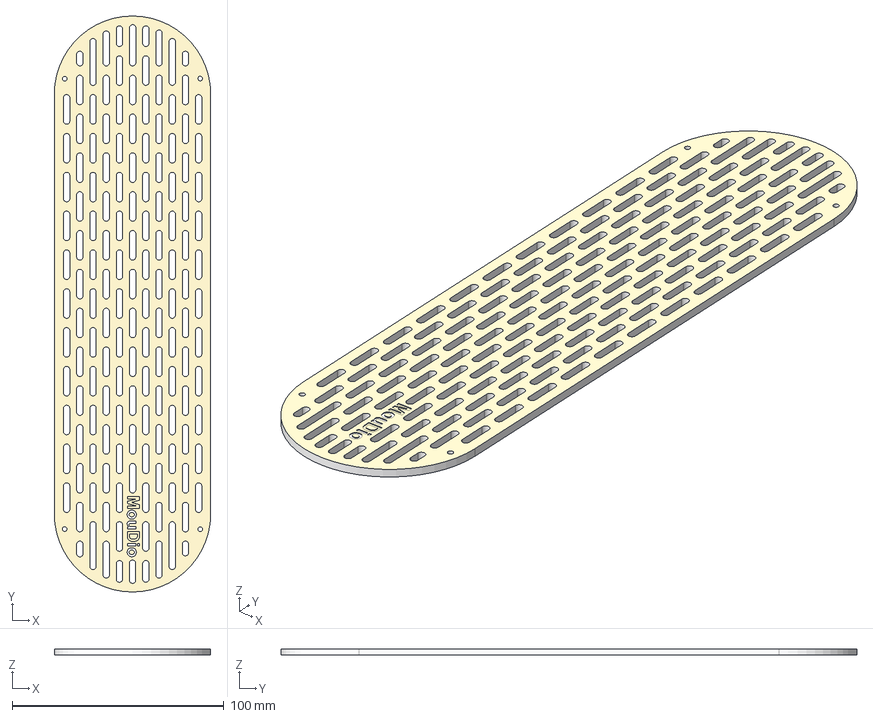
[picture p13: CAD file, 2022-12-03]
3D-Files/Grill/4/Front Pattern 4.step
74.0 x 272.2 x 3.00 mm

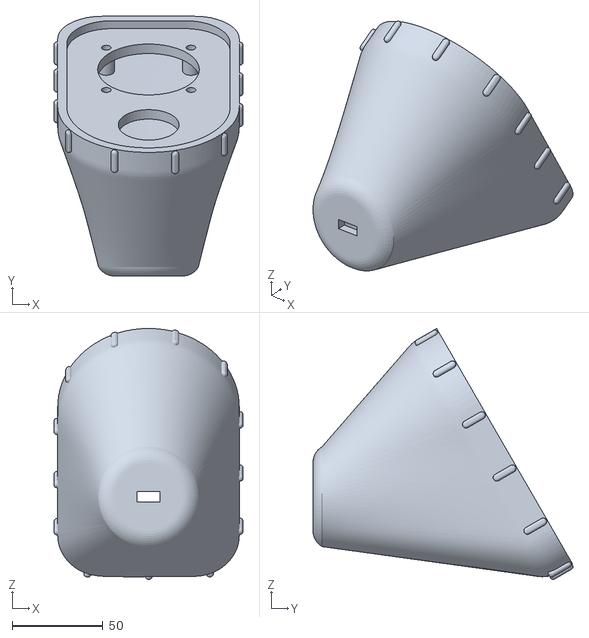
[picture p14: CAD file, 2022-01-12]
Prototype/STL-Files/Sealed Woofer + Twrt Speaker Test/speaker with twtr test.stl
104.0 x 143.2 x 138.2

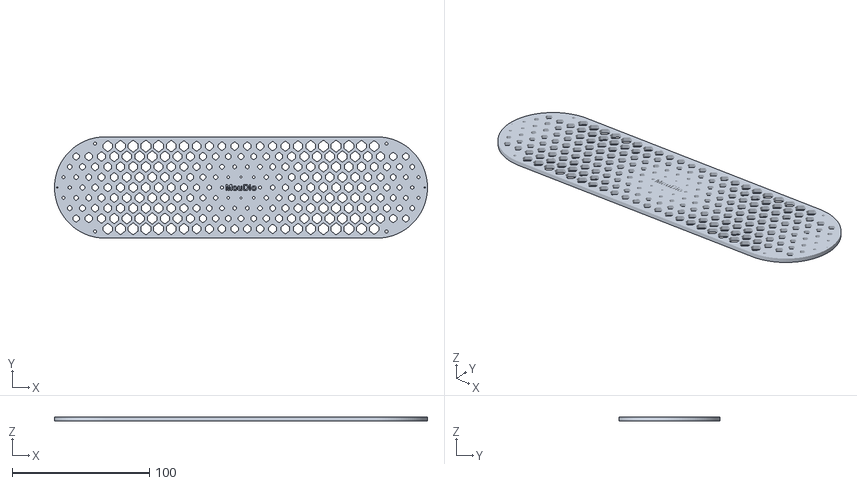
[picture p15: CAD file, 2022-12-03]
3D-Files/Grill/1/Front Pattern 1.stl
272.2 x 74.0 x 3.00

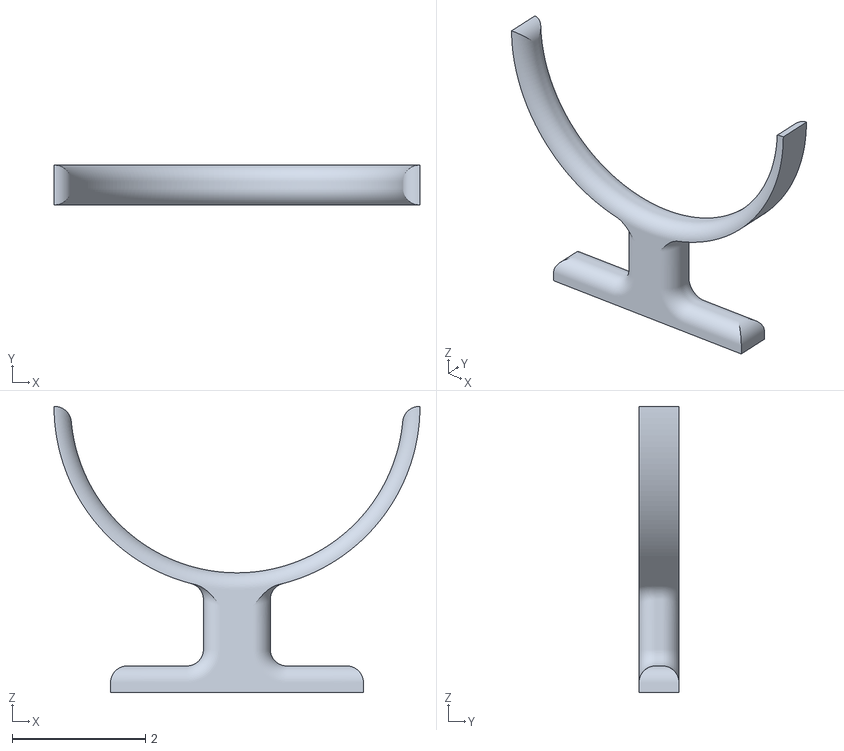
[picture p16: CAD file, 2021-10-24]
Prototype/STL-Files/Sealed Woofer Speaker Test/Holder.stl
5.50 x 0.6 x 4.30

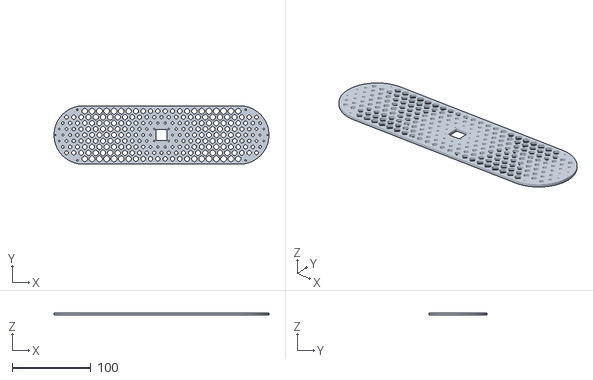
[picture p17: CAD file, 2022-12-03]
3D-Files/Grill/1/Back Pattern 1.stl
272.2 x 74.0 x 3.00

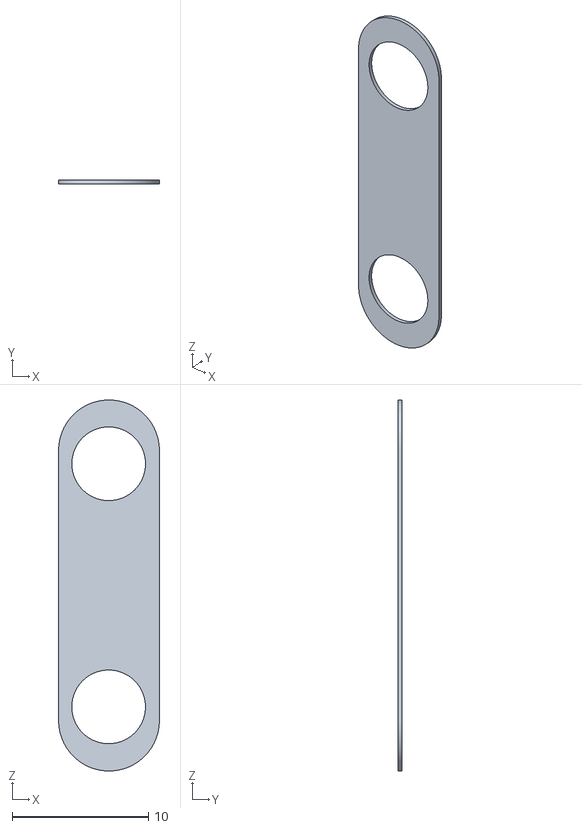
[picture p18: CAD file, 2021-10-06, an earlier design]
Prototype/Old Version/Hardware/Laser Cut/Front small.stl
7.39 x 0.3 x 27.2

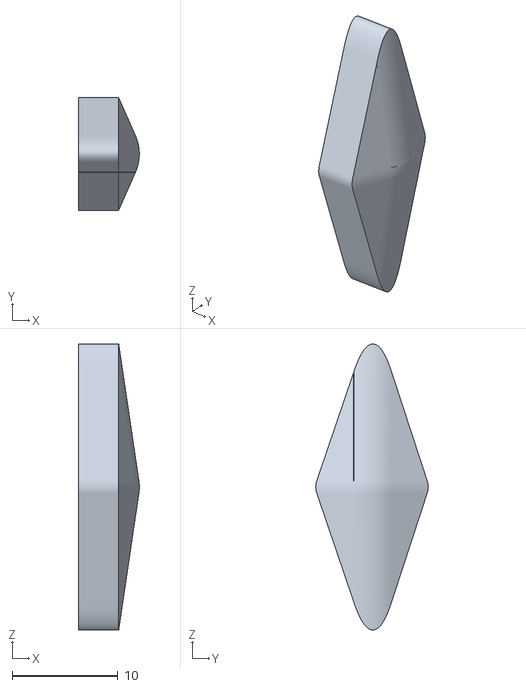
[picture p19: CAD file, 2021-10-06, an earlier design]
Prototype/Old Version/STL-Files/Push Button.stl
5.75 x 10.7 x 27.1

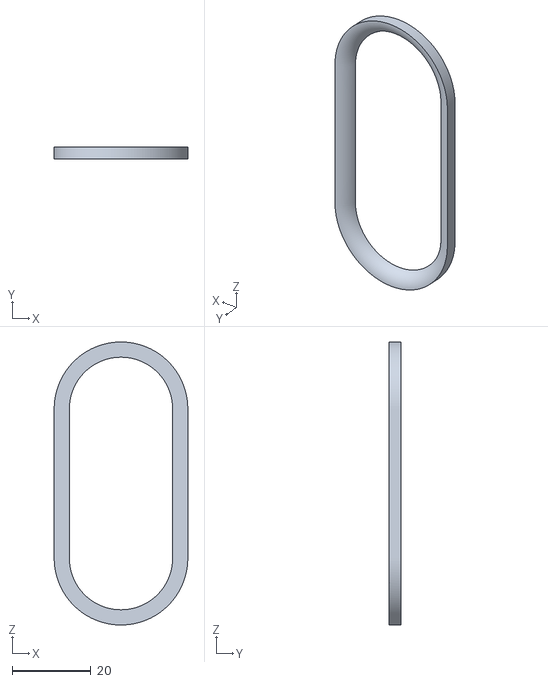
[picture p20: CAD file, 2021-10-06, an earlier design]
Prototype/Old Version/STL-Files/Passive Radiator Holder.stl
34.0 x 3.00 x 72.0

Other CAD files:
3D-Files/Grill/1/Back Pattern 1.dxf
3D-Files/Grill/1/Front Pattern 1.dxf
3D-Files/Grill/2/Front Pattern 2.dxf
3D-Files/Grill/2/Front Pattern 2.stl
3D-Files/Grill/3/Front Pattern 3.dxf
3D-Files/Grill/4/Front Pattern 4.dxf
3D-Files/Grill/4/Front Pattern 4.iges
3D-Files/Grill/4/Front Pattern 4.stl
Prototype/Old Version/Hardware/Laser Cut/front small.dxf

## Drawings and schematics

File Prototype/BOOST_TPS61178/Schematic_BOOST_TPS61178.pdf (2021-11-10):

## BOOST CONVERTER TPS61178

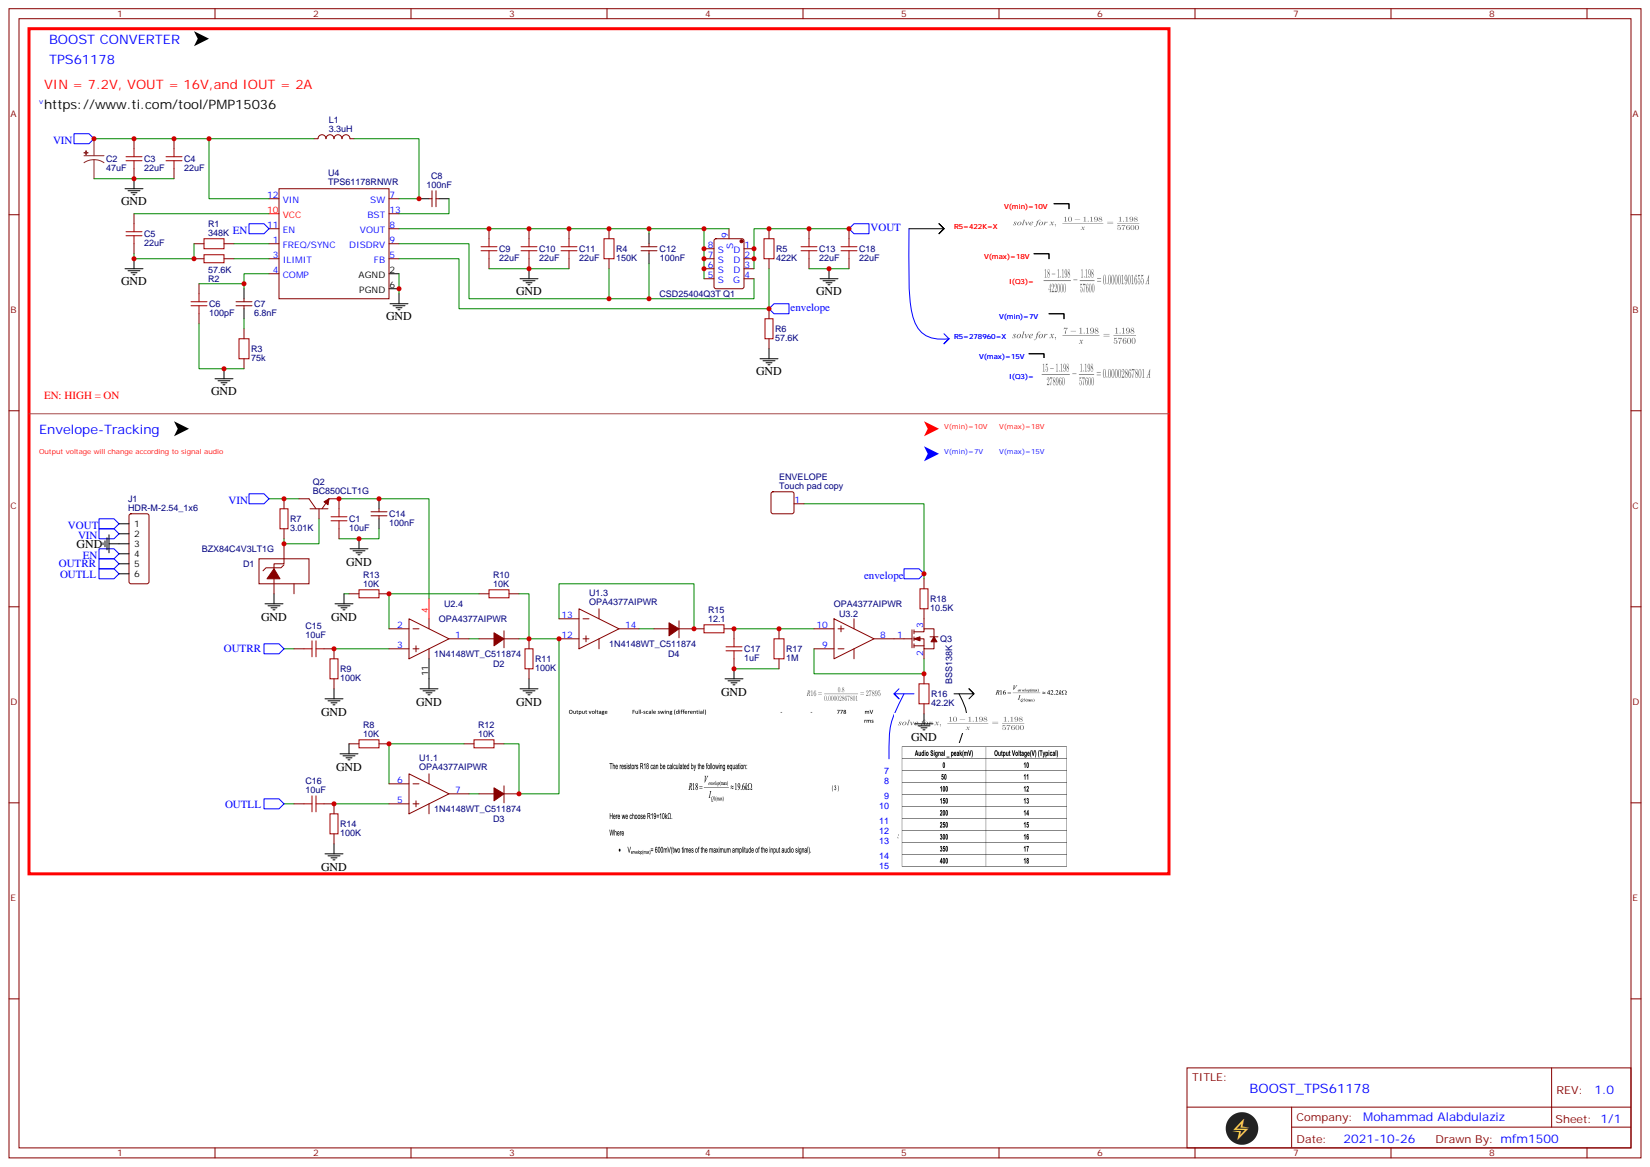
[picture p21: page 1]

VIN = 7.2V, VOUT = 16V,and IOUT = 2A
https://www.ti.com/tool/PMP15036

Output voltage will change according to signal audio

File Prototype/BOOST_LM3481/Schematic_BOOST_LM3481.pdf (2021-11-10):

## BOOST CONVERTER

LM3481

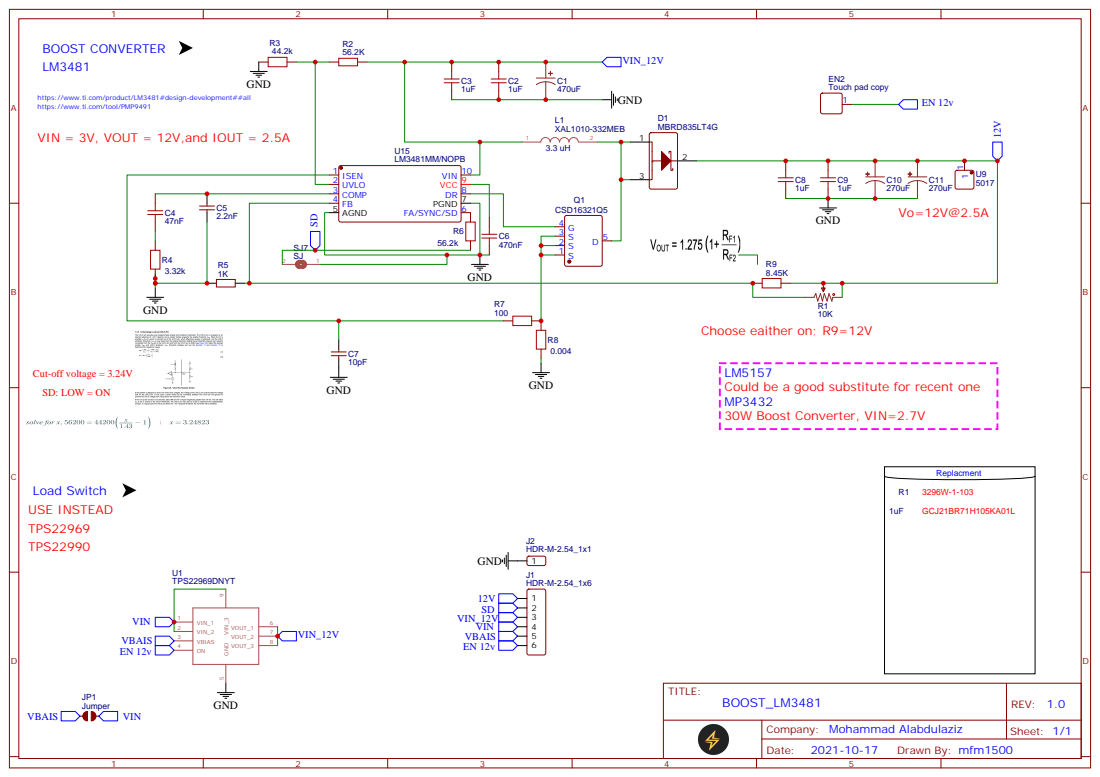
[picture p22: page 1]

https://www.ti.com/product/LM3481#design-development##all
VIN = 3V, VOUT = 12V,and IOUT = 2.5A

https://www.ti.com/tool/PMP9491

Could be a good substitute for recent one
30W Boost Converter, VIN=2.7V

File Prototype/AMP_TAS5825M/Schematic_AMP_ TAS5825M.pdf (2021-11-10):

## Amplifier TAS5825M

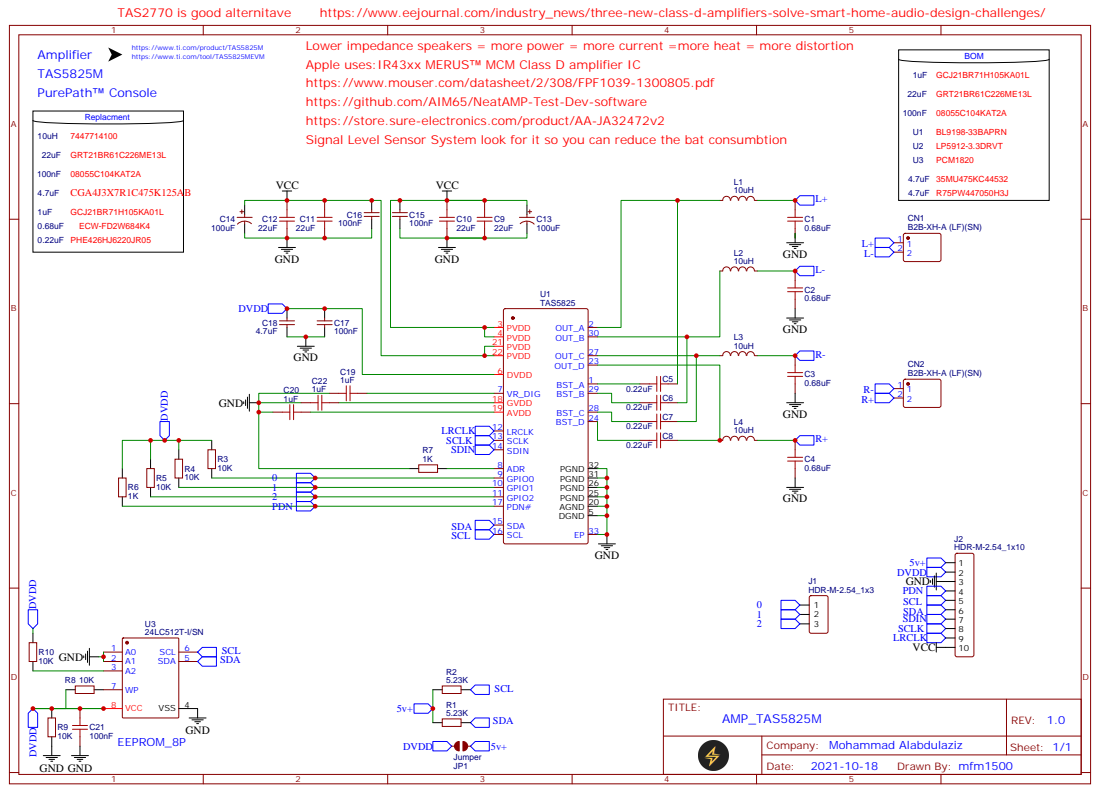
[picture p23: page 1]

Lower impedance speakers = more power = more current =more heat = more distortion
Apple uses:IR43xx MERUS MCM Class D amplifier IC
https://www.mouser.com/datasheet/2/308/FPF1039-1300805.pdf
https://github.com/AIM65/NeatAMP-Test-Dev-software
https://store.sure-electronics.com/product/AA-JA32472v2
Signal Level Sensor System look for it so you can reduce the bat consumbtion

https://www.ti.com/product/TAS5825M
https://www.ti.com/tool/TAS5825MEVM

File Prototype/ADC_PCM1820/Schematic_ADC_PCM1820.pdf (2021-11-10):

## PCM1820

## ADC

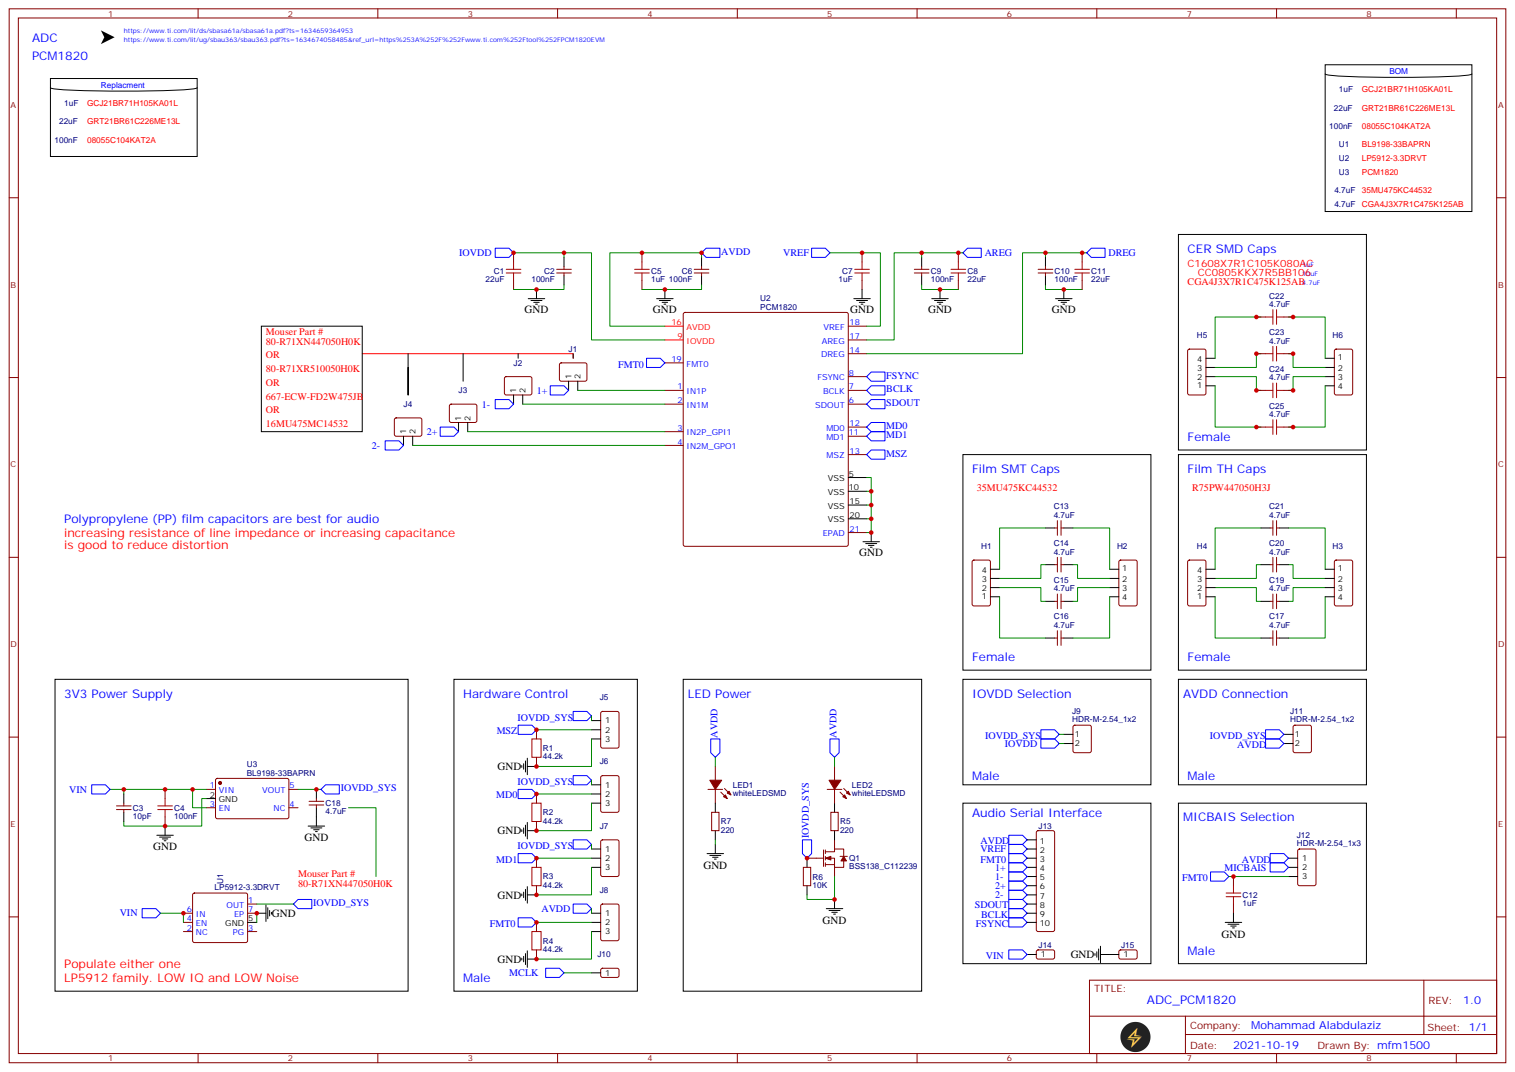
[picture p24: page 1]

https://www.ti.com/lit/ds/sbasa61a/sbasa61a.pdf?ts=1634659364953
https://www.ti.com/lit/ug/sbau363/sbau363.pdf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

Polypropylene (PP) film capacitors are best for audio
increasing resistance of line impedance or increasing capacitance
is good to reduce distortion

Populate either one
LP5912 family. LOW IQ and LOW Noise

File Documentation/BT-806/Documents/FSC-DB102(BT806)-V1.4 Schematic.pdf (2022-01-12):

## EN Pin（MUTE）

# TRBI 200 Port

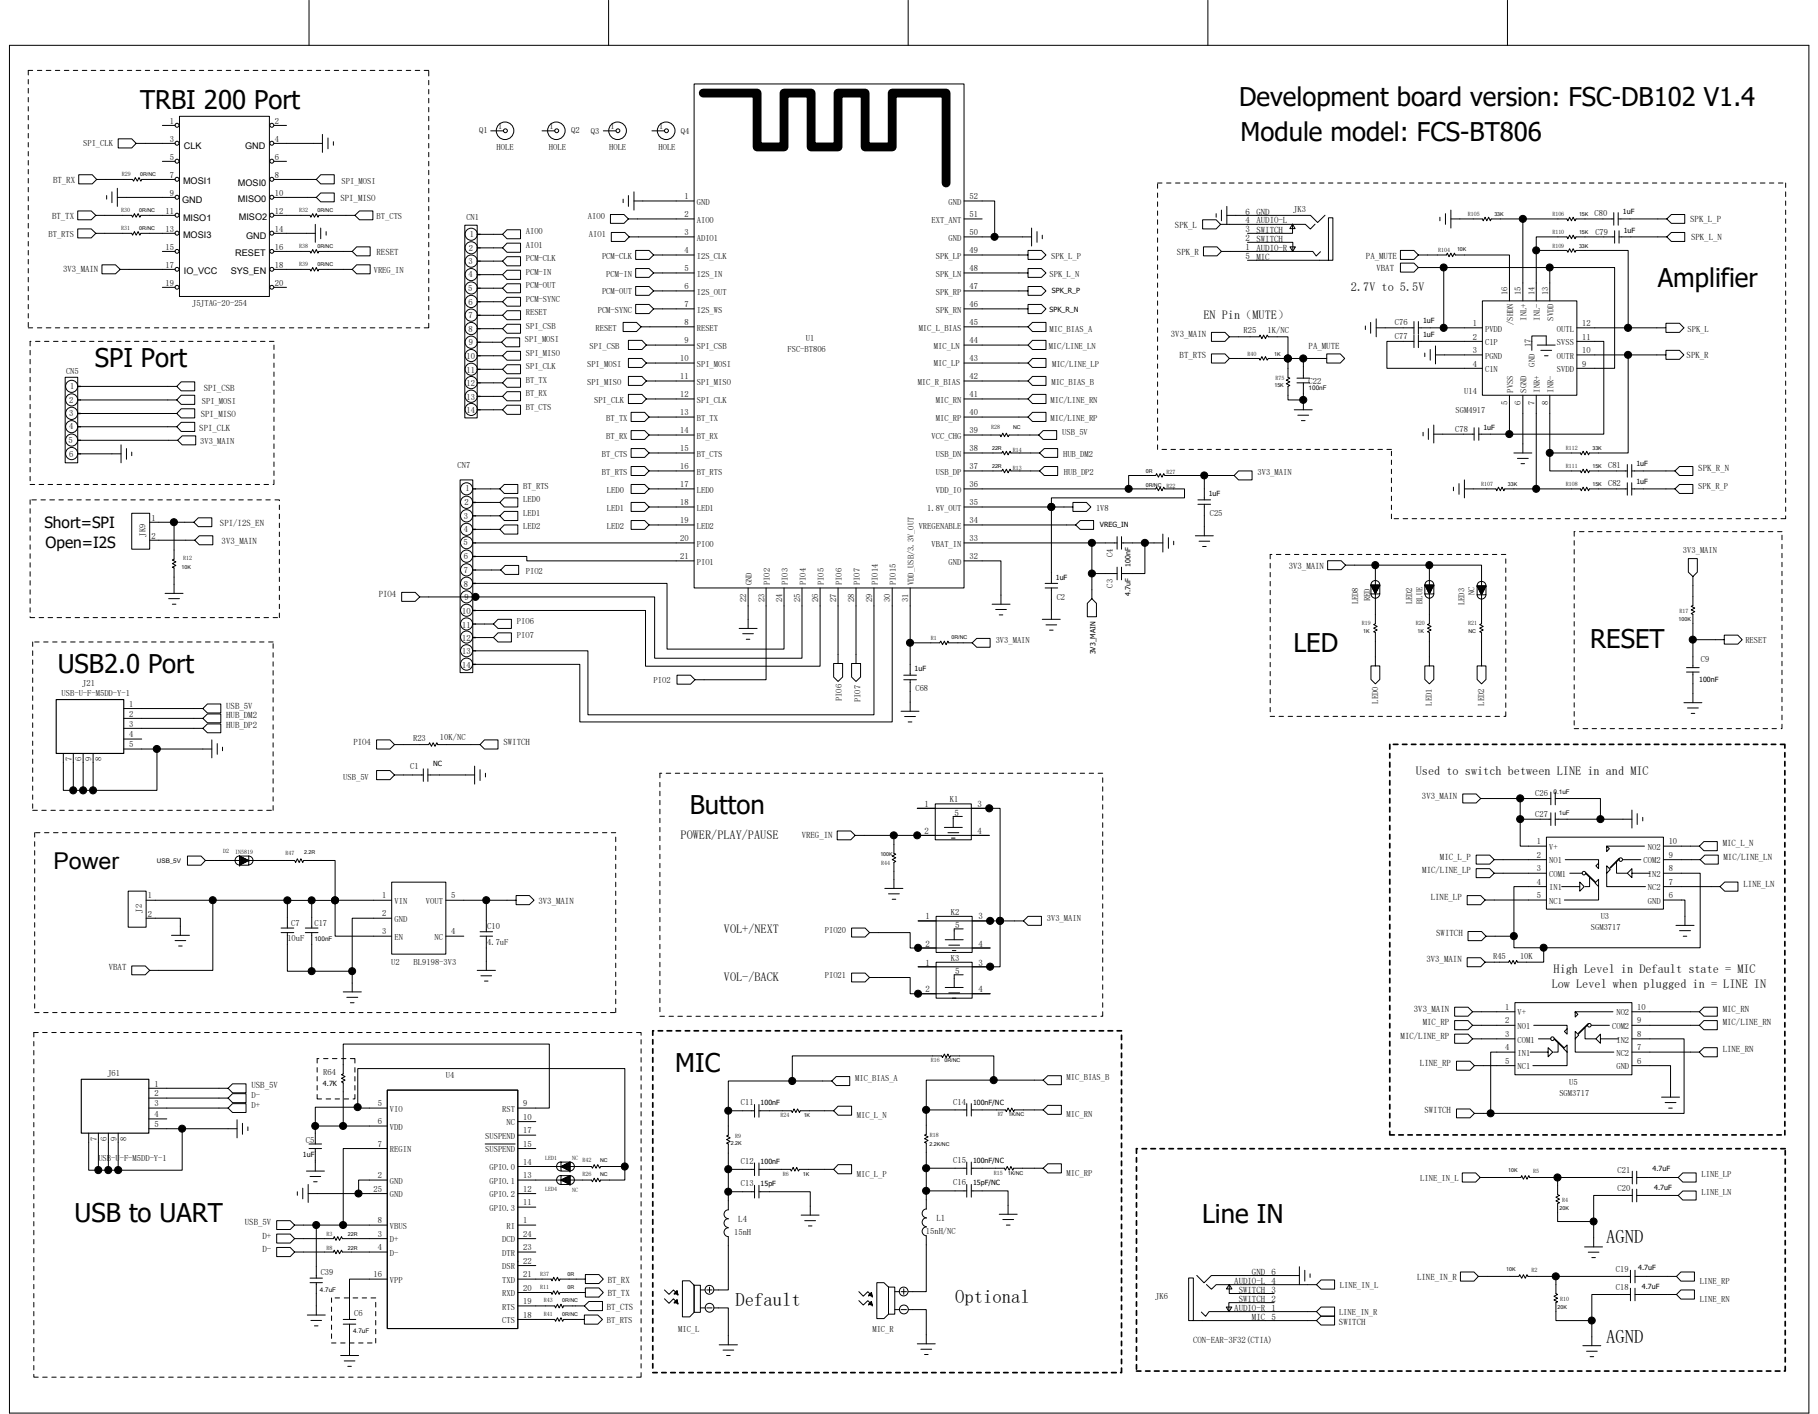
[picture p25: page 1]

Development board version: FSC-DB102 V1.4
Module model: FCS-BT806

5 PVSS 6 SGND 7 INR+ 8 INR-

Used to switch between LINE in and MIC

High Level in Default state = MIC
Low Level when plugged in = LINE IN

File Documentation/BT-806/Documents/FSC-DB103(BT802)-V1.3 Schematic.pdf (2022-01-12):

## Used to switch between LINE in and MIC

## High Level in Default state = MIC

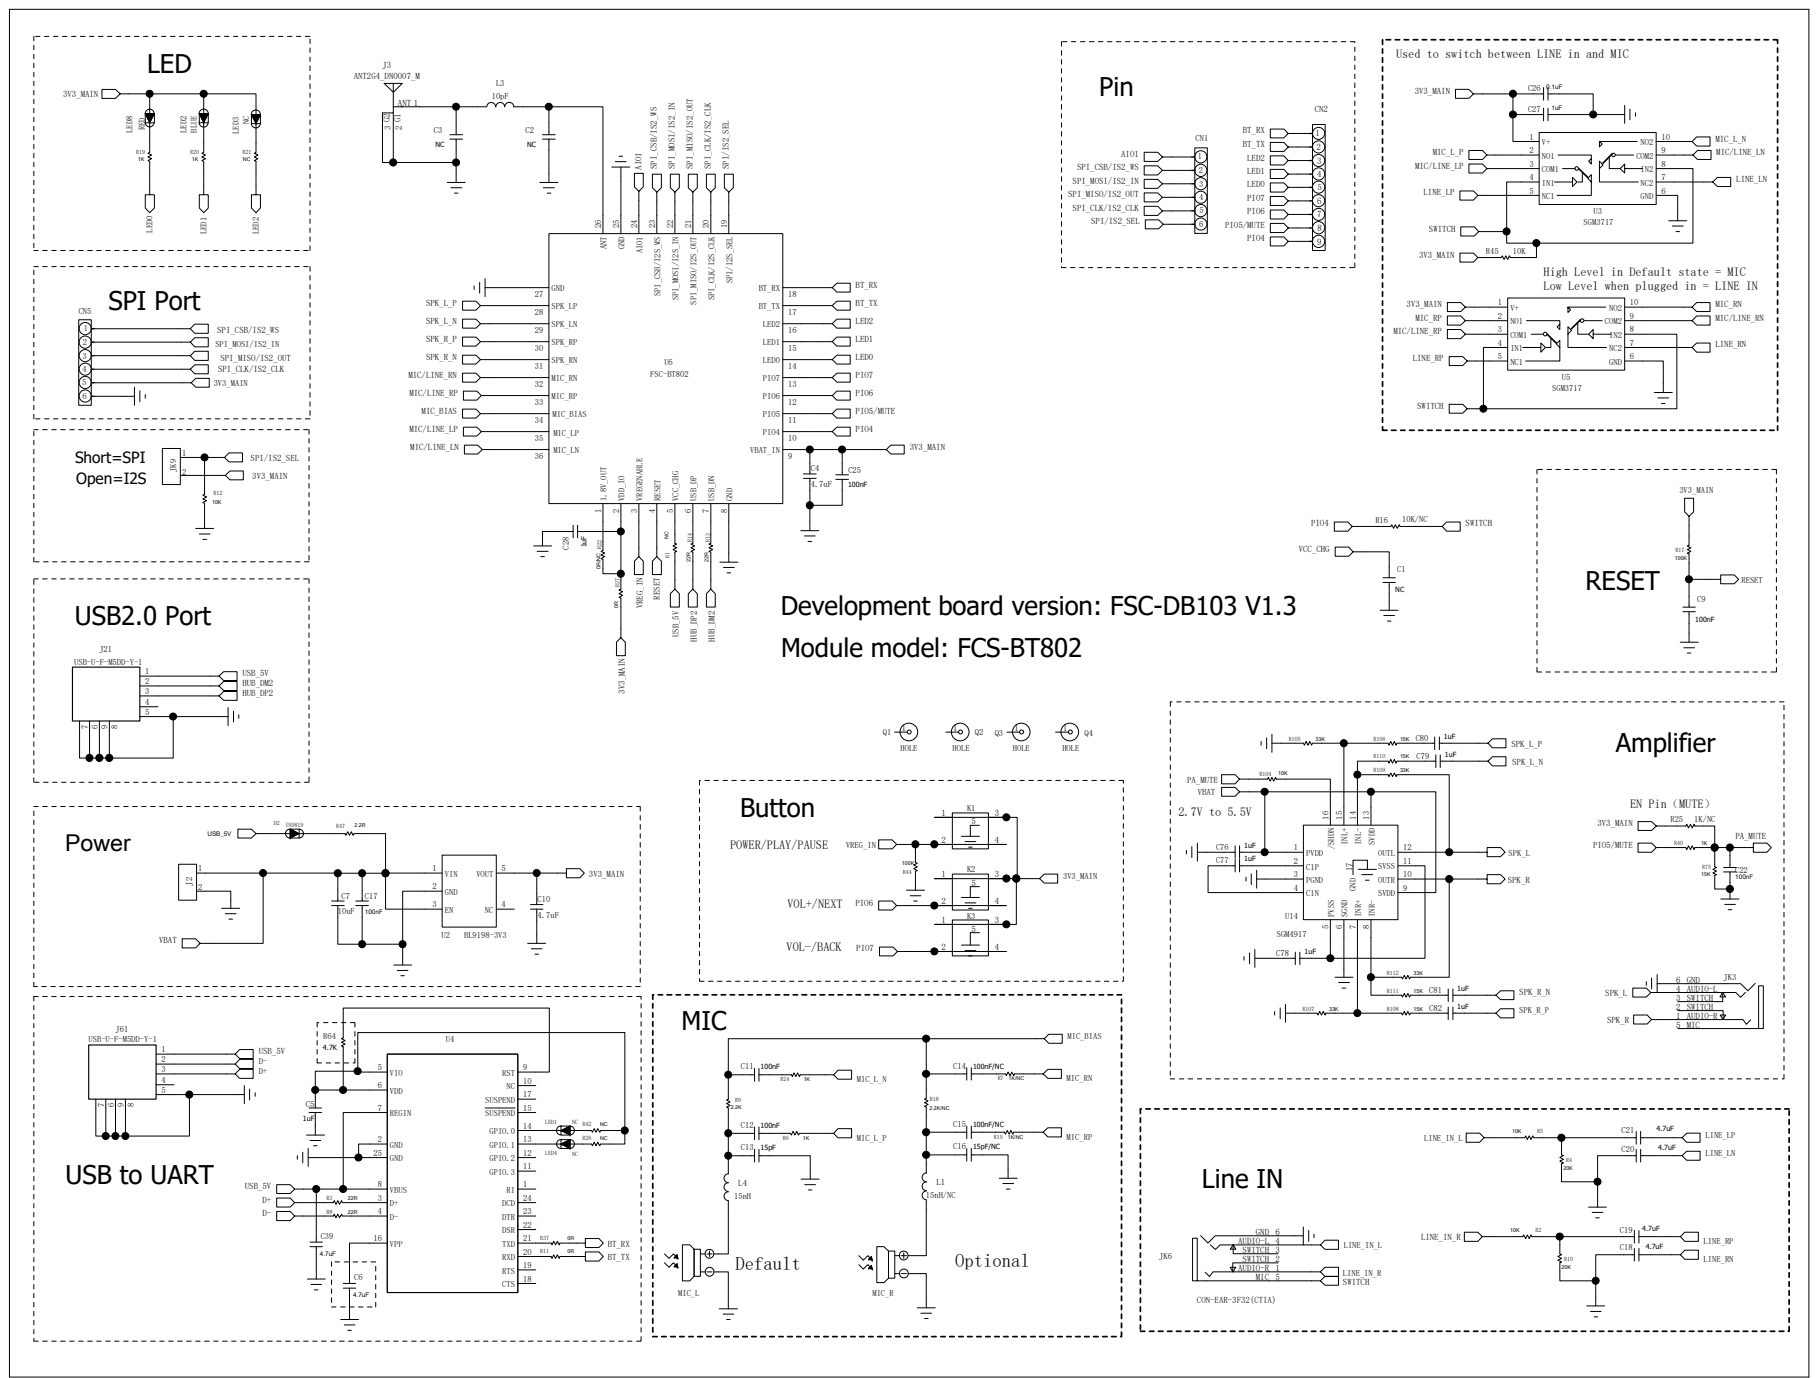
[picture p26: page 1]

Low Level when plugged in = LINE IN

Development board version: FSC-DB103 V1.3
Module model: FCS-BT802

5 PVSS 6 SGND 7 INR+ 8 INR-

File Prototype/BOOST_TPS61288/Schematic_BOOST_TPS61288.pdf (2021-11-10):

## BOOST CONVERTER TPS61288

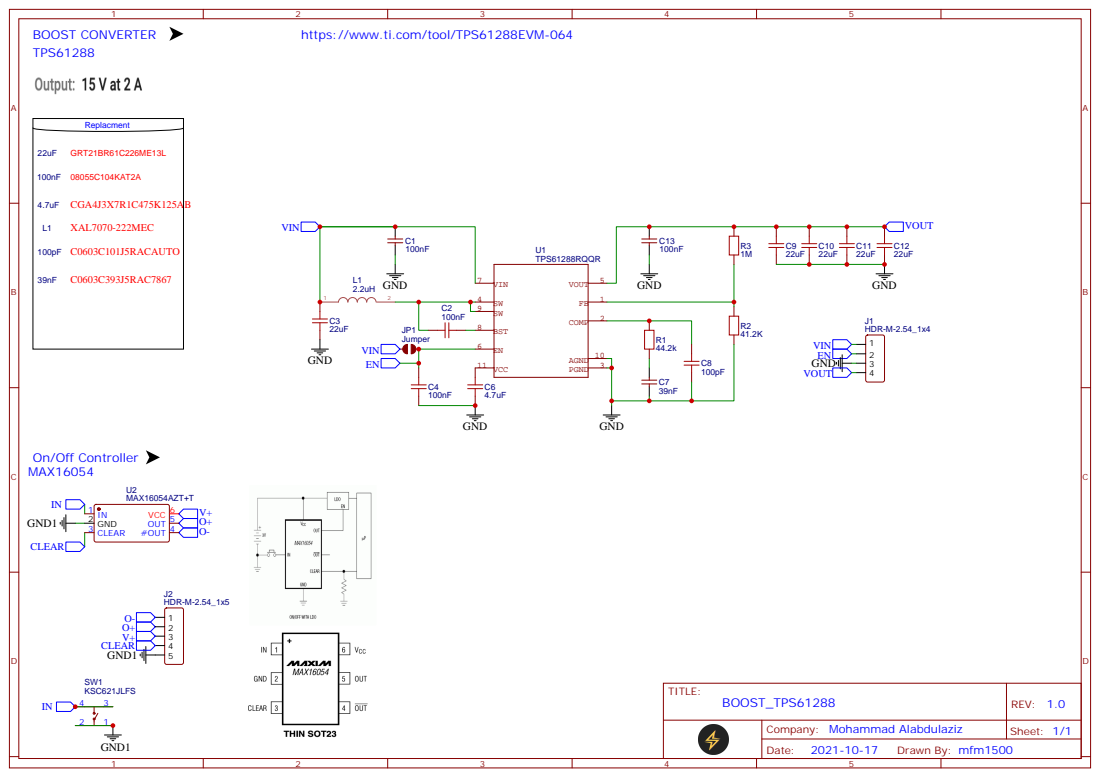
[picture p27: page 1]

https://www.ti.com/tool/TPS61288EVM-064

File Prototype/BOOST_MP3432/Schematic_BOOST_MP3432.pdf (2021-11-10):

MP3432

## BOOST CONVERTER

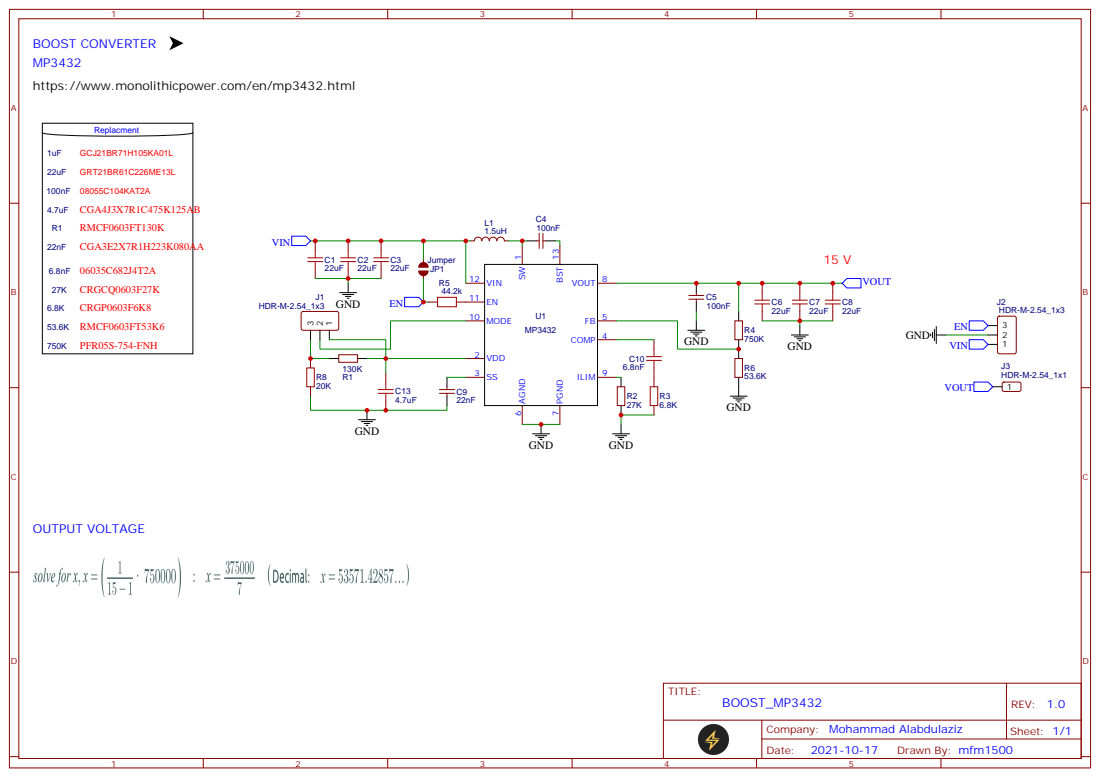
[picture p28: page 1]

https://www.monolithicpower.com/en/mp3432.html

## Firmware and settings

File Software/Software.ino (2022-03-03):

#include "Amplifier.h"
#include "MAX17043.h"
#include <avr/sleep.h>
#include <Wire.h>
#include "Adafruit_DRV2605.h"

//#include <FastLED.h>
//#include <Adafruit_NeoPixel.h>
//#define LED_PIN     10 //
//#define NUM_LEDS    52
//#define LED_TYPE    WS2812B
//#define COLOR_ORDER GRB
//CRGB leds[NUM_LEDS]; 
//test


//-------------------------------------------------BT-806--------------------------------------------
char* readLine(char c)
{ // parameter 'c' ==> character that was read
  // return NULL ==> line not ready yet
  // return pointer ==> points to received lineBuffer
  static char lineBuffer[25]; // define maximum string length + terminating '\0'
  static byte counter = 0;
  if (counter == 0) memset(lineBuffer, 0, sizeof(lineBuffer)); // clear buffer before using it
  if (c < 32) // non printable control character, line finished
  {
    if (counter == 0) return NULL;
    counter = 0;
    return lineBuffer;
  }
  else if (counter < sizeof(lineBuffer) - 1) // printable character received and we have room for it
  {
    lineBuffer[counter] = c; // insert character into lineBuffer
    counter++; // increment character counter
  }
  return NULL;
}
//---------------------------------------------------------------------------------------------------

// Instantiate Amplifier object, name it anything, in this case 'TAS5825'
Amplifier TAS5825; //Amplifier
Adafruit_DRV2605 drv; //LED Driver


const int pinLED = 12; //As an indiscation of ON/OFF SYS
const int lowLED = 11; //As an indiscation of low bat
const int pinSwitch = 2; //ON/OFF
const int Pinchargecon = 3; //intrupt for input charger
const int Next = 6; //Next
const int Back = 7; //Back
const int Up = 5; //Up+
const int Down = 4; //Down-
float Low_Bat;

byte
currSwitch,
lastSwitch,charge=0,last_state;
unsigned long
timeStart;
bool
bCheckingSwitch;

// Variables will change:
int ledState = LOW; // ledState used to set the LED
// The value will quickly become too large for an int to store
unsigned long previousMillis = 0; // will store last time LED was updated

// constants won't change:
const long interval = 1000; // interval at which to blink (milliseconds)



void setup() {
  // put your setup code here, to run once:
  Serial.begin(115200);
  FuelGauge.begin();
  drv.begin();
  drv.selectLibrary(1);
  drv.setWaveform(0, 84);  // ramp up medium 1, see datasheet part 11.2
  drv.setWaveform(1, 1);  // strong click 100%, see datasheet part 11.2
  drv.setWaveform(2, 0);  // end of waveforms
  pinMode( pinLED, OUTPUT );
  pinMode( lowLED, OUTPUT );
  digitalWrite( pinLED, LOW );
  pinMode( pinSwitch, INPUT_PULLUP );
  lastSwitch = digitalRead( pinSwitch );
  bCheckingSwitch = false;

  TAS5825.init();
  TAS5825.init_IS31FL3195();
  TAS5825.Mode_IS31FL3195();
  TAS5825.put_bat_voltage();
//
// Serial.println(TAS5825.get_bat_stat(), BIN);
//  Serial.println(TAS5825.getCHG_DETAILS_02(), BIN);
}

void loop() {

  wake_BTN ();
  CTRL_BTN ();
  Low_Bat_AMP ();
  SHOW_BAT_LEDS ();

///////////////////////READINGS///////////////////////
 unsigned long currentMillis = millis();
  if ( currentMillis - previousMillis >= 5000 ) {

   Serial.println("MAX17320 Parameter : \n===============================================================");
   Serial.print("SOC % : \t\t");
   Serial.print( TAS5825.BATpercent() );
   Serial.print("%   \t\t");


   Serial.print("\nBATT  : \t\t");
   Serial.print( TAS5825.getPCKP() );
   Serial.print("V   \t\t");


   Serial.print("\nAvgVCell  : \t\t");
   Serial.print( TAS5825.getAvgVCell() );
   Serial.print("V   \t\t");


   Serial.print("\nRemaining Capacity  : \t\t");
   Serial.print( TAS5825.getRepCap() );
   Serial.print("mA   \t\t");

   Serial.print("\nTemperature  : \t\t");
   Serial.print( TAS5825.getTemp() );
   Serial.print("C   \t\t");


      Serial.println();
      previousMillis = currentMillis;

    }
}


void wake_BTN () {
  //read the switch (for simplicity, no debouncing done)
  currSwitch = digitalRead( pinSwitch );

  if ( currSwitch != lastSwitch )
  {
    //if low now, the change was unpressed to pressed
    if ( currSwitch == HIGH )
    {
      //in that case, get the time now to start the
      //5-sec delay...
      timeStart = millis();
      //...indicate we're now timing a press...
      bCheckingSwitch = true;
    }//if
    else
    {
      bCheckingSwitch = false;
     }//else

    //and save the
    lastSwitch = currSwitch;
  }
  if ( bCheckingSwitch )
  {
    //if the millis count now is 5000 or more higher
    //than it was when the press was detected (timeStart),
    //turn on the LED
    if ( (millis() - timeStart ) < 1000 ){
      Serial.println("AT+PLAYPAUSE");

    }
    else if ((millis() - timeStart ) >= 3000) {
      Serial.println("Going to sleep");
      drv.go();
      delay(500);//sleep time
      digitalWrite( pinLED, LOW );
//      TAS5825.Vol_Down();
      delay(1000);//sleep time

      sleep_CPU();
    }
  }
}


void CTRL_BTN () {
  //To control TPR54
  delay(100);
  int sensorVal1 = digitalRead(Next);
  if (sensorVal1 == HIGH) {
    Serial.println("AT+FORWARD");
    TAS5825.show_led_Next();//
    delay(1000);//sleep time
    SHOW_BAT_LEDS ();
  bat_pres_solid();
      SHOW_BAT_LEDS ();

  }


  int sensorVal2 = digitalRead(Back);
  if (sensorVal2 == HIGH) {
    Serial.println("AT+BACKWARD");
  }

  int sensorVal3 = digitalRead(Up);
  if (sensorVal3 == HIGH) {
    Serial.println("AT+SPKVOL=+");
  }

  int sensorVal4 = digitalRead(Down);
  if (sensorVal4 == HIGH) {
    Serial.println("AT+SPKVOL=-");
  }
}


 void SHOW_BAT_LEDS () {

byte cha_state=0;
  cha_state=TAS5825.get_bat_stat();

 if(cha_state & 0x01 ){
 // Serial.println("fi");
    charge=1;
  }
  else{
    charge=0;
  }

  if(cha_state & 0x02){
   // Serial.println("se");
    charge=1;
  }
  else{
    charge=0;
  }
  if(charge != last_state)
  {last_state=charge;
   if(charge==0){
  bat_pres_solid();}
  else{
    bat_pres();
    //Serial.println(charge, BIN);
  }}
//Serial.println(cha_state, BIN);


}


void Low_Bat_AMP (void) {
  Low_Bat = TAS5825.getPVDD_ADC() / 8.4;
  if (Low_Bat < 6 && Low_Bat > 1) {
    unsigned long currentMillis = millis();

    if (currentMillis - previousMillis >= interval) {
      previousMillis = currentMillis;
      if (ledState == LOW) {
        ledState = HIGH;
      } else {
        ledState = LOW;
      }
      digitalWrite(lowLED, ledState);
    }
  }
  else {
    digitalWrite(lowLED, LOW);
  }
}

void bat_pres(void){
  uint16_t pres=0;
   pres = FuelGauge.percent();
   Serial.println(pres);
   if((pres>=0) && (pres<25)){
    TAS5825.show_led_0();
   }
   else if((pres>=25) && (pres<50)){
    TAS5825.show_led_25();
   }
   else if((pres>=50) && (pres<75)){
    TAS5825.show_led_50();
   }
   else if((pres>=75) && (pres<95)){
    TAS5825.show_led_75();
   }
   else if(pres>96){
    TAS5825.show_led_100();
   }
}

void bat_pres_solid(void){
  uint16_t pres=0;
   pres = FuelGauge.percent();
   Serial.println(pres);
   if((pres>=0) && (pres<25)){
    TAS5825.show_led_0_flash();
   }
   else if((pres>=25) && (pres<50)){
    TAS5825.show_led_25_solid();
   }
   else if((pres>=50) && (pres<75)){
    TAS5825.show_led_50_solid();
   }
   else if((pres>=75) && (pres<95)){
    TAS5825.show_led_75_solid();
   }
   else if(pres>96){
    TAS5825.show_led_100_solid();
   }
}

void wake_CPU (void) {

  // cancel sleep as a precaution
  sleep_disable();
  // precautionary while we do other stuff
charge=0;
  detachInterrupt (0);
  detachInterrupt (1);
  delay(100);
  Serial.println("Wake_all");
  interrupts ();
  interrupts ();
  interrupts ();
  pinMode(2, INPUT);
  pinMode(3, INPUT);
  drv.go();
  delay(500);//sleep time
  digitalWrite( pinLED, HIGH );
  TAS5825.wake_AMP();
  TAS5825.otg_off();
 bat_pres_solid();// I ADDED THIS
  delay(1000);
}  // end of wake

void wake_CPU_LED (void) {

  // cancel sleep as a precaution
  sleep_disable();
  // precautionary while we do other stuff
charge=1;
  //detachInterrupt (0);
  detachInterrupt (1);
  delay(100);
  Serial.println("Wake_LED");
  interrupts ();
  interrupts ();
  interrupts ();
  //pinMode(2, INPUT);
  //pinMode(3, INPUT);
  //drv.go();
  delay(500);//sleep time
  //digitalWrite( pinLED, HIGH );
  if(digitalRead(3)==HIGH){
    charge=0;
    TAS5825.sleep_led();
  }
  else{
    charge=1;
    bat_pres();
  }

   //attachInterrupt (1, wake_CPU_LED, CHANGE);
  //EIFR = bit (INTF1);  // clear flag for interrupt 0
  // We are guaranteed that the sleep_cpu call will be done
  // as the processor executes the next instruction after
  // interrupts are turned on.
  //noInterrupts ();
 // set_sleep_mode (SLEEP_MODE_PWR_DOWN);
 // sleep_enable();
  //interrupts ();  // one cycle
  //TAS5825.show_LED();
  sleep_CPU();
  //TAS5825.wake_AMP();
  //delay(1000);
}  // end of wake

void sleep_CPU(void)
{
  TAS5825.sleep_AMP();
// Do not interrupt before we go to sleep, or the
// ISR will detach interrupts and we won't wake.
  TAS5825.otg_off();

  // will be called when pin D0 goes low
  Serial.println("Sleep");
  delay(100);
  EIFR = bit (INTF0);

  attachInterrupt (0, wake_CPU, CHANGE);
  EIFR = bit (INTF0);
// attachInterrupt (1, wake_CPU_LED, CHANGE);
  if(charge==0){
  TAS5825.sleep_led();
   EIFR = bit (INTF1);
  attachInterrupt (1, wake_CPU_LED, CHANGE);}
  else{EIFR = bit (INTF1);attachInterrupt (1, wake_CPU_LED, RISING);}
  EIFR = bit (INTF1);  // clear flag for interrupt 0
// We are guaranteed that the sleep_cpu call will be done
// as the processor executes the next instruction after
// interrupts are turned on.
  noInterrupts ();
  set_sleep_mode (SLEEP_MODE_PWR_DOWN);
  sleep_enable();
  interrupts ();  // one cycle
  sleep_cpu ();   // one cycle
}

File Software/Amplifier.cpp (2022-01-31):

/* My comments */

#include "Amplifier.h"
#include <Wire.h>
#include <avr/sleep.h>

// Amplifier object
Amplifier::Amplifier() {
}

/////////////////////TAS5825M//////////////////////
void Amplifier::init()  {
    Wire.begin();
    //  Wire.setClock(400000);//I2C 400kHz
    // Header file for PurePath3 to set up the AMP as desired
    writeReg8(TAS5825M_ADDRESS, 0x00, 0x00);
    writeReg8(TAS5825M_ADDRESS, 0x7f, 0x00);
    writeReg8(TAS5825M_ADDRESS, 0x03, 0x02);
    writeReg8(TAS5825M_ADDRESS, 0x01, 0x11);
    writeReg8(TAS5825M_ADDRESS, 0x00, 0x00);
    writeReg8(TAS5825M_ADDRESS, 0x00, 0x00);
    writeReg8(TAS5825M_ADDRESS, 0x00, 0x00);
    writeReg8(TAS5825M_ADDRESS, 0x00, 0x00);
    writeReg8(TAS5825M_ADDRESS, 0x00, 0x00);

    writeReg8(TAS5825M_ADDRESS, 0x7f, 0x00);
    writeReg8(TAS5825M_ADDRESS, 0x7d, 0x11);
    writeReg8(TAS5825M_ADDRESS, 0x7e, 0xff);
    writeReg8(TAS5825M_ADDRESS, 0x00, 0x01);
    writeReg8(TAS5825M_ADDRESS, 0x51, 0x05);
    writeReg8(TAS5825M_ADDRESS, 0x00, 0x02);
    writeReg8(TAS5825M_ADDRESS, 0x19, 0xa0);
    writeReg8(TAS5825M_ADDRESS, 0x1d, 0x01);
    writeReg8(TAS5825M_ADDRESS, 0x00, 0x00);
    writeReg8(TAS5825M_ADDRESS, 0x7f, 0x00);
    writeReg8(TAS5825M_ADDRESS, 0x46, 0x01);
    writeReg8(TAS5825M_ADDRESS, 0x00, 0x00);
    writeReg8(TAS5825M_ADDRESS, 0x02, 0x40);// DEVICE_CTRL_1
    writeReg8(TAS5825M_ADDRESS, 0x53, 0x60);
    writeReg8(TAS5825M_ADDRESS, 0x54, 0x00);
    writeReg8(TAS5825M_ADDRESS, 0x00, 0x00);
    writeReg8(TAS5825M_ADDRESS, 0x7f, 0x00);
    writeReg8(TAS5825M_ADDRESS, 0x03, 0x02);

        delay(5);

    writeReg8(TAS5825M_ADDRESS, 0x00, 0x00);
    writeReg8(TAS5825M_ADDRESS, 0x00, 0x00);
    writeReg8(TAS5825M_ADDRESS, 0x00, 0x00);
    writeReg8(TAS5825M_ADDRESS, 0x00, 0x00);
    writeReg8(TAS5825M_ADDRESS, 0x7f, 0x8c);
    writeReg8(TAS5825M_ADDRESS, 0x00, 0x06);
    writeReg8(TAS5825M_ADDRESS, 0x38, 0x00);
    writeReg8(TAS5825M_ADDRESS, 0x39, 0x00);
    writeReg8(TAS5825M_ADDRESS, 0x3a, 0x04);
    writeReg8(TAS5825M_ADDRESS, 0x3b, 0x00);

    //Tuning coeffs

    writeReg8(TAS5825M_ADDRESS, 0x00, 0x0b);
    writeReg8(TAS5825M_ADDRESS, 0x50, 0x00);
    writeReg8(TAS5825M_ADDRESS, 0x51, 0x20);
    writeReg8(TAS5825M_ADDRESS, 0x52, 0xc4);
    writeReg8(TAS5825M_ADDRESS, 0x53, 0x9c);
    writeReg8(TAS5825M_ADDRESS, 0x5c, 0x7f);
    writeReg8(TAS5825M_ADDRESS, 0x5d, 0xff);
    writeReg8(TAS5825M_ADDRESS, 0x5e, 0xff);
    writeReg8(TAS5825M_ADDRESS, 0x5f, 0xff);

    // Book 0x8c

    writeReg8(TAS5825M_ADDRESS, 0x00, 0x00);
    writeReg8(TAS5825M_ADDRESS, 0x7f, 0x8c);

    writeReg8(TAS5825M_ADDRESS, 0x00, 0x01);
    writeReg8(TAS5825M_ADDRESS, 0x28, 0x40);
    writeReg8(TAS5825M_ADDRESS, 0x29, 0x00);
    writeReg8(TAS5825M_ADDRESS, 0x2a, 0x00);
    writeReg8(TAS5825M_ADDRESS, 0x2b, 0x00);

    writeReg8(TAS5825M_ADDRESS, 0x00, 0x0a);
    writeReg8(TAS5825M_ADDRESS, 0x64, 0x00);
    writeReg8(TAS5825M_ADDRESS, 0x65, 0x80);
    writeReg8(TAS5825M_ADDRESS, 0x66, 0x00);
    writeReg8(TAS5825M_ADDRESS, 0x67, 0x00);
    writeReg8(TAS5825M_ADDRESS, 0x68, 0x00);
    writeReg8(TAS5825M_ADDRESS, 0x69, 0x00);
    writeReg8(TAS5825M_ADDRESS, 0x6a, 0x00);
    writeReg8(TAS5825M_ADDRESS, 0x6b, 0x00);
    writeReg8(TAS5825M_ADDRESS, 0x6c, 0x00);
    writeReg8(TAS5825M_ADDRESS, 0x6d, 0x00);
    writeReg8(TAS5825M_ADDRESS, 0x6e, 0x00);
    writeReg8(TAS5825M_ADDRESS, 0x6f, 0x00);
    writeReg8(TAS5825M_ADDRESS, 0x70, 0x00);
    writeReg8(TAS5825M_ADDRESS, 0x71, 0x00);
    writeReg8(TAS5825M_ADDRESS, 0x72, 0x00);
    writeReg8(TAS5825M_ADDRESS, 0x73, 0x00);
    writeReg8(TAS5825M_ADDRESS, 0x74, 0x00);
    writeReg8(TAS5825M_ADDRESS, 0x75, 0x80);
    writeReg8(TAS5825M_ADDRESS, 0x76, 0x00);
    writeReg8(TAS5825M_ADDRESS, 0x77, 0x00);
    writeReg8(TAS5825M_ADDRESS, 0x78, 0x00);
    writeReg8(TAS5825M_ADDRESS, 0x79, 0x00);
    writeReg8(TAS5825M_ADDRESS, 0x7a, 0x00);
    writeReg8(TAS5825M_ADDRESS, 0x7b, 0x00);
    writeReg8(TAS5825M_ADDRESS, 0x7c, 0x00);
    writeReg8(TAS5825M_ADDRESS, 0x7d, 0x00);
    writeReg8(TAS5825M_ADDRESS, 0x7e, 0x00);
    writeReg8(TAS5825M_ADDRESS, 0x7f, 0x00);

    writeReg8(TAS5825M_ADDRESS, 0x00, 0x0b);
    writeReg8(TAS5825M_ADDRESS, 0x08, 0x00);
    writeReg8(TAS5825M_ADDRESS, 0x09, 0x80);
    writeReg8(TAS5825M_ADDRESS, 0x0a, 0x00);
    writeReg8(TAS5825M_ADDRESS, 0x0b, 0x00);

    writeReg8(TAS5825M_ADDRESS, 0x38, 0x02);
    writeReg8(TAS5825M_ADDRESS, 0x39, 0xa3);
    writeReg8(TAS5825M_ADDRESS, 0x3a, 0x9a);
    writeReg8(TAS5825M_ADDRESS, 0x3b, 0xcc);
    writeReg8(TAS5825M_ADDRESS, 0x3c, 0x00);
    writeReg8(TAS5825M_ADDRESS, 0x3d, 0x06);
    writeReg8(TAS5825M_ADDRESS, 0x3e, 0xd3);
    writeReg8(TAS5825M_ADDRESS, 0x3f, 0x72);

    writeReg8(TAS5825M_ADDRESS, 0x48, 0x04);
    writeReg8(TAS5825M_ADDRESS, 0x49, 0xc1);
    writeReg8(TAS5825M_ADDRESS, 0x4a, 0xff);
    writeReg8(TAS5825M_ADDRESS, 0x4b, 0x93);
    writeReg8(TAS5825M_ADDRESS, 0x4c, 0x01);
    writeReg8(TAS5825M_ADDRESS, 0x4d, 0x12);
    writeReg8(TAS5825M_ADDRESS, 0x4e, 0x6e);
    writeReg8(TAS5825M_ADDRESS, 0x4f, 0x98);

    writeReg8(TAS5825M_ADDRESS, 0x54, 0x7b);
    writeReg8(TAS5825M_ADDRESS, 0x55, 0x3e);
    writeReg8(TAS5825M_ADDRESS, 0x56, 0x00);
    writeReg8(TAS5825M_ADDRESS, 0x57, 0x6d);
    writeReg8(TAS5825M_ADDRESS, 0x58, 0x00);
    writeReg8(TAS5825M_ADDRESS, 0x59, 0x00);
    writeReg8(TAS5825M_ADDRESS, 0x5a, 0xae);
    writeReg8(TAS5825M_ADDRESS, 0x5b, 0xc3);

    writeReg8(TAS5825M_ADDRESS, 0x60, 0x08);
    writeReg8(TAS5825M_ADDRESS, 0x61, 0x13);
    writeReg8(TAS5825M_ADDRESS, 0x62, 0x85);
    writeReg8(TAS5825M_ADDRESS, 0x63, 0x62);
    writeReg8(TAS5825M_ADDRESS, 0x64, 0x00);
    writeReg8(TAS5825M_ADDRESS, 0x65, 0x80);
    writeReg8(TAS5825M_ADDRESS, 0x66, 0x00);
    writeReg8(TAS5825M_ADDRESS, 0x67, 0x00);

    writeReg8(TAS5825M_ADDRESS, 0x6c, 0x00);
    writeReg8(TAS5825M_ADDRESS, 0x6d, 0x78);
    writeReg8(TAS5825M_ADDRESS, 0x6e, 0xd6);
    writeReg8(TAS5825M_ADDRESS, 0x6f, 0xfd);
    writeReg8(TAS5825M_ADDRESS, 0x70, 0x00);
    writeReg8(TAS5825M_ADDRESS, 0x00, 0x00);
    writeReg8(TAS5825M_ADDRESS, 0x71, 0x08);
    writeReg8(TAS5825M_ADDRESS, 0x72, 0x13);
    writeReg8(TAS5825M_ADDRESS, 0x73, 0x85);

    //Register Tuning

    writeReg8(TAS5825M_ADDRESS, 0x00, 0x00);
    writeReg8(TAS5825M_ADDRESS, 0x7f, 0x00);
    writeReg8(TAS5825M_ADDRESS, 0x30, 0x00);
    writeReg8(TAS5825M_ADDRESS, 0x60, 0x02);
    writeReg8(TAS5825M_ADDRESS, 0x62, 0x09);
    writeReg8(TAS5825M_ADDRESS, 0x4c, 0x30);
    writeReg8(TAS5825M_ADDRESS, 0x03, 0x03);
    writeReg8(TAS5825M_ADDRESS, 0x00, 0x00);
    writeReg8(TAS5825M_ADDRESS, 0x7f, 0x00);
    writeReg8(TAS5825M_ADDRESS, 0x78, 0x80);
  }

void Amplifier::wake_AMP(void){
// Seq to turn ON the AMP
    writeReg8(TAS5825M_ADDRESS, DEVICE_CTRL_2, B00000010);//Hiz
    delay(10);
    writeReg8(TAS5825M_ADDRESS, DEVICE_CTRL_2, B00000011);//Play
    writeReg8(TAS5825M_ADDRESS, DIG_VOL, 0x30);//-0.5 dB
     }
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

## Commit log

2021-10-06 The four Push Buttons
    This is a newer version of the Push Buttons (Still under the process)
    [Push Button.stl]
2021-10-06 Create Laser Cut
2022-02-09 Update HW Files
    [Front v1.f3z, Front v1.sch, Front_v1.brd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]

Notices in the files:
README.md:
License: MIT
